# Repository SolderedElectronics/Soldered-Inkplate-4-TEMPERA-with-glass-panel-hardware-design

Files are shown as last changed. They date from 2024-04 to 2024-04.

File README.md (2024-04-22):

## Soldered Inkplate 4 TEMPERA with glass panel hardware design

|  |
| :----------------------------------------------------------: |
|      [Soldered Inkplate 4 TEMPERA with glass panel](https://soldered.com/product/soldered-inkplate-4-tempera/)      |

Inkplate 4 TEMPERA is an easy-to-use, all-in-one device that puts the power of e-paper technology in the palm of your hand. Behind its 3.8-inch, 600×600-pixel e-paper touchscreen, it packs the following features into one compact, elegant package: frontlighting, an abundance of sensors, Wi-Fi and Bluetooth connectivity, a built-in battery, and a low-power operating mode.

## Repository contents

All Soldered hardware is designed in KiCAD, and repositories are organized in the following way:

- CAD folder - contains KiCAD files (Schematics, Board, Panel Board), organized by version. Change log lists all changes between versions.
- OUTPUTS - contains useful files, such as Bill of Materials (BOM), PDF of schematics, 3D .step file of the board and gerber files, organized by version. 

## Want to contribute?

All contributions are welcome, feel free to submit the pull request. If you discover a bug, please submit an issue or pull request. 

## About Soldered

Soldered logo

At Soldered, we design and manufacture a wide selection of electronic products to help you turn your ideas into acts and bring you one step closer to your final project. Our products are intented for makers and crafted in-house by our experienced team in Osijek, Croatia. We believe that sharing is a crucial element for improvement and innovation, and we work hard to stay connected with all our makers regardless of their skill or experience level. Therefore, all our products are open-source. Finally, we always have your back. If you face any problem concerning either your shopping experience or your electronics project, our team will help you deal with it, offering efficient customer service and cost-free technical support anytime. Some of those might be useful for you:

- [Web Store](https://www.soldered.com)
- [Tutorials & Projects](https://learn.soldered.com)
- [Community & Technical support](https://community.soldered.com)
- [Custom PCBs](https://pcb.soldered.com)

## License info

All Soldered open-source hardware (OSH) is under The TAPR Open Hardware License. Read more in the LICENSE file. 

No warranty - all designs in this repository are distributed in the hope that they will be useful, but without any warranty. They are provided "AS IS", therefore without warranty of any kind, either expressed or implied. The entire quality and performance of what you do with the contents of this repository are your responsibility. In no event, Soldered (TAVU) will be liable for your damages, losses, including any general, special, incidental or consequential damage arising out of the use or inability to use the contents of this repository. 

Thank you from your fellow makers at Soldered.

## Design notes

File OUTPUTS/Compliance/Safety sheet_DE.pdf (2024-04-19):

BITTE BEWAHREN SIE DIESE INFORMATIONEN ZUR SPÄTEREN VERWENDUNG AUF.
LESEN SIE VOR DER VERWENDUNG DIESES PRODUKTS ALLE ANWEISUNGEN IN DOKUMENT. Produktname: Inkplate 4 TEMPERA
Die ersten Schritte: Besuchen Sie www.soldered.com, um loszulegen.

## WARNUNGEN

- Dieses Produkt sollte nicht abgedeckt werden und in einer gut belüfteten Umgebung betrieben werden.
- Das Produkt sollte auf einer stabilen, flachen, nicht leitenden Oberfläche aufgestellt werden und nicht mit leitenden Gegenständen in Berührung kommen.
- Der Anschluss anderer Geräte kann die Konformität beeinträchtigen oder zu Schäden am Gerät führen und zum Erlöschen der Garantie führen.
- Wenn Peripheriegeräte angeschlossen werden, die nicht das Kabel oder den Stecker enthalten, muss das verwendete Kabel oder muss das verwendete Kabel bzw. der verwendete Steckverbinder eine angemessene Isolierung und Funktion aufweisen, damit die Anforderungen die einschlägigen Leistungs- und Sicherheitsanforderungen erfüllt werden.
- Es besteht Explosionsgefahr, wenn die Batterie falsch eingesetzt wird.
- Das Produkt sollte nicht außerhalb des angegebenen Arbeitsbereichs verwendet werden.

## HINWEISE ZUR SICHEREN ANWENDUNG

Um Fehlfunktionen oder Schäden an Ihrem Gerät zu vermeiden, beachten Sie bitte die folgenden Hinweise:
- Setzen Sie das Gerät nicht Wasser oder Feuchtigkeit aus und stellen Sie es nicht auf eine
leitende Oberfläche, wenn es eingeschaltet ist. Das Gerät nicht mit nassen Händen anfassen.
- Setzen Sie es keiner Wärmequelle aus; das Produkt ist für die Verwendung bei normalen Raumtemperaturen ausgelegt. Das Produkt ist für die Verwendung in Innenräumen vorgesehen.
- Seien Sie bei der Handhabung vorsichtig, um mechanische oder elektrische Schäden an Teilen des Geräts zu vermeiden. Fassen Sie das Gerät nicht an, wenn es unter Spannung steht. Verwenden Sie einen ESD-Schutz.
- Verwenden Sie nur das mitgelieferte Kabel (oder ein gleich- oder höherwertiges Kabel)
mit dem Gerät.

## COMPLIANCE-INFORMATIONEN

Das Produkt entspricht den entsprechenden Bestimmungen der RoHS-Richtlinie für die Europäische Union. Wie alle elektrischen und elektronischen Geräte (EEE), sollte das Produkt nicht über den Hausmüll entsorgt werden.
ELEKTROMAGNETISCHE VERTRÄGLICHKEIT UND BETRIEB
- Das Produkt entspricht den Schutzanforderungen der Richtlinie des EU-Rates 2014/30/EU über die Rechtsvorschriften der Mitgliedstaaten zur elektromagnetischen Verträglichkeit und den Elektromagnetische Verträglichkeitsverordnung 2016 des Vereinigten Königreichs.
- WARNUNG: Bitte verändern Sie nicht das Design dieses Produkts, da dies dazu führen kann, dass Sie das Produkt nicht mehr uneingeschränkt nutzen können.
Dies gilt auch für die Änderung der Frequenz, mit der das Produkt arbeitet.

## Einhaltung gesetzlicher Vorschriften und wichtige

Soldered Electronics d.o.o., Reisnerova ulica 100, 31000 Osijek, Croatia. VAT ID: HR83200237288

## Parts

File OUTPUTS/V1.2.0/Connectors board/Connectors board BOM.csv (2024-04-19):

Id | Designator | Package | Quantity | Designation | Supplier and ref
1 | H1,H4,H2,H3 | HOLE_3.2mm | 4 | HOLE_3.2mm
2 | K5 | JS05A-40P-050-3-4 | 1 | JS05A-40P-050-3-4
3 | K3 | SFV34R-3STBE1HLF | 1 | SFV34R-3STBE1HLF
4 | R1 | 0603R | 1 | 100k
5 | C4,C7,C3,C5,C6 | 0805C | 5 | 4u7-TMK212AB7475KG-T
6 | C1,C8 | 0603C | 2 | 100n
7 | K4 | 62684-401100AHLF | 1 | 62684-402100AHLF
8 | K1 | SFV6R-1STBE1HLF | 1 | SFV6R-1STBE1HLF
9 | C2 | 0603C | 1 | 4u7
10 | K6 | SFV6R-1STBE1HLF | 1 | DNP
11 | K2 | SFV8R-1STBE1HLF | 1 | SFV8R-1STBE1HLF

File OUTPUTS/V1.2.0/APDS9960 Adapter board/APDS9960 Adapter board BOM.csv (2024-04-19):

Id | Designator | Package | Quantity | Designation | Supplier and ref
1 | R1 | 0603R | 1 | 10k
2 | C2 | 0603C | 1 | 100n
3 | C1 | 0603C | 1 | 1u
4 | U1 | APDS-9960 | 1 | APDS-9960
5 | C3 | 1206C | 1 | 10u
6 | PAD4,PAD3,PAD5,PAD1,PAD2 | PAD_2x1.5 | 5 | PAD_2x1.5

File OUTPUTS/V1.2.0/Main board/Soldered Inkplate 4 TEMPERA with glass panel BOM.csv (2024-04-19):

Id | Designator | Package | Quantity | Designation | Supplier and ref
1 | U10 | TXS0104EPWR | 1 | TXS0104EPWR
2 | D3,D5,D10,D4 | SOD-323 | 4 | BAT20J
3 | K22,K25,K31,K28,K24,K9,K30,K20,K41,K32,K26,K19,K35,K38,K34,K8,K37,K36,K14,K13,K7,K29,K40,K16,K23,K15,K17,K39,K6,K5,K21,K18,K27,K33 | HEADER_MALE_1X1_Inkplate | 34 | HEADER_MALE_1X1_Inkplate
4 | S1 | SK-3296S-01-L1 | 1 | SK-3296S-01-L1
5 | R17,R18,R49 | 0603R | 3 | 5k1
6 | C13,C4,C3,C12,C8,C11,C7,C1,C5,C2 | 0805C | 10 | 4u7-TMK212AB7475KG-T
7 | K4 | easyC-connector | 1 | easyC-SMD
8 | C41,C42,C59,C40,C49,C51,C63,C58,C53,C61,C65,C23,C45,C60,C32,C38,C27,C64,C22,C35,C26,C47,C68,C48,C57,C62,C33,C66 | 0603C | 28 | 100n
9 | K42,K43 | APDS_connector | 2 | APDS_connector
10 | PAD4,PAD2,PAD3,PAD5,PAD1 | PAD_4x4 | 5 | PAD_4x4
11 | R19,R34,R21,R35,R33,R31 | 0603R | 6 | 1k
12 | R39,R38,R42,R41,R36,R3,R43,R52,R47,R44,R5,R51,R53,R60,R4,R37 | 0603R | 16 | 100k
13 | C15,C14 | 0603C | 2 | 2u2-GRM188R61E225MA12D
14 | R10,R6,R8,R9,R7 | 0603R | 5 | 4k7
15 | R11 | 0603R | 1 | NTC-NCP18XH103F03RB
16 | SW3,SW2 | K2-1114SA-A4SW-06 | 2 | K2-1114SA-A4SW-06
17 | JP1,JP4 | SMD_JUMPER | 2 | SMD_JUMPER
18 | R2,R1,R46,R55,R58,R54,R56,R28,R40,R57,R61 | 0603R | 11 | 10k
19 | JP2 | SMD_JUMPER_3_PAD_CONNECTED_RIGHT_TRACE | 1 | SMD_JUMPER_3_PAD_CONNECTED_RIGHT_TRACE
20 | C30,C54 | 2917C | 2 | DNP
21 | SW1 | YTSA007A0151803B | 1 | YTSA007A0151803B
22 | R15,R13 | 0603R | 2 | 1M
23 | C17,C16 | 0603C | 2 | 10n-AC0603KRX7R8BB103
24 | R32 | 0603R | 1 | 47R
25 | C34,C39,C31,C67,C24,C21,C56 | 0603C | 7 | 2u2
26 | H4,H2,H1,H3 | HOLE_3.2mm | 4 | HOLE_3.2mm
27 | K3 | JST-2pin-SMD | 1 | JST-2pin-SMD
28 | JP5 | SMD-JUMPER-CONNECTED_TRACE_SOLDERMASK | 1 | SMD-JUMPER-CONNECTED_TRACE_SOLDERMASK
29 | D9 | LTST-S270GKT | 1 | 0603LED_SIDE
30 | JP6,JP3 | SMD_JUMPER_3_PAD_CONNECTED_LEFT_TRACE | 2 | SMD_JUMPER_3_PAD_CONNECTED_LEFT_TRACE
31 | U19 | BME688 | 1 | BME688
32 | R12 | 0603R | 1 | 43k-RC0603FR-0743KL
33 | Q6,Q7 | SOT-23-3 | 2 | SSM3J358R,LF
34 | U15,U13 | PCAL6416AHF,128 | 2 | PCAL6416AHF,128
35 | Q8,Q11,Q12,Q14,Q9,Q4,Q13 | SOT-23-3 | 7 | PMOS
36 | K10 | HYC77-TF09-200 | 1 | HYC77-TF09-200
37 | U20 | MLT-7525 | 1 | MLT-7525
38 | F1 | 1206FUSE | 1 | 1206FUSE-500mA
39 | D8 | 0402LED | 1 | RED
40 | C9,C10,C6 | 0603C | 3 | 10u-GRM188R61E106KA73J
41 | K11 | CR2032-BS-6-1 | 1 | CR2032_BS-6-1
42 | K1 | INKPLATE TEST HEADER | 1 | Inkplate_TP
43 | K2 | U262-161N-4BVC11 | 1 | U262-161N-4BVC11
44 | D7,D6 | SOT-23-3 | 2 | BAT54S
45 | R63,R26,R20 | 0603R | 3 | DNP
46 | C19,C18 | 0603C | 2 | 100n-AC0603KRX7R8BB104
47 | R16 | 0603R | 1 | 47k5-RC0603FR-0747K5L
48 | C55,C20,C25 | 1206C | 3 | 10u
49 | D11,D12 | M4_DIODA | 2 | M4_DIODA
50 | C36,C37 | 0603C | 2 | 12p
51 | C28 | 0603C | 1 | 470n
52 | U17 | LSM6DSO32TR | 1 | LSM6DS3TR
53 | U6 | SOP-16 | 1 | CH340C
54 | D1,D2 | SOD-323-2 | 2 | CUS10F30,H3F
55 | U2 | SOT-23-5 | 1 | MCP73831T
56 | D13 | SOD-523 | 1 | RB510SM-40FHT2R
57 | U14 | ESP32-WROVER | 1 | ESP32-WROVER
58 | U11 | SN74LVC1G34DBV | 1 | SN74LVC1G34DBV
59 | C52,C50 | 0805C | 2 | CL21B105KBFNNNG
60 | U3 | TPS7A2633DRVR | 1 | TPS7A2633DRVR
61 | Q5,Q3,Q2 | SOT-23-3 | 3 | NPN
62 | L3 | NR4012 | 1 | NR4012T220M
63 | C43 | 0603C | 1 | 4u7
64 | R24 | 0603R | 1 | PA0603FRE570R01L
65 | R30,R29 | 0603R | 2 | 33k
66 | Q15,Q10 | SOT-23-3 | 2 | NMOS
67 | U8 | PCF85063A | 1 | PCF85063A
68 | C46 | 0603C | 1 | 100p
69 | K12 | 62684-401100AHLF | 1 | 62684-401100AHLF
70 | X1 | ABS07AIG-32.768KHZ-7-D-T | 1 | 7LC32768F12UC
71 | R14 | 0603R | 1 | 52k3-RC0603FR-0752K3L
72 | R23 | 0603R | 1 | 2k49
73 | C29,C44 | 0603C | 2 | 1u
74 | U16 | SC70-6 | 1 | MCP4017T-103E/LT
75 | L1 | 1515L | 1 | LQH44PN4R7MP0L
76 | R22 | 0603R | 1 | 0R
77 | U7 | TSSOP-14 | 1 | MC14093BDTR2G
78 | U4 | SOT-23-5 | 1 | TPS3840PL27DBVR
79 | R62 | 0603R | 1 | 22
80 | U9 | MCP47A1-SOT23-6 | 1 | MCP47A1
81 | R48 | 0603R | 1 | 15R
82 | R27,R50 | 0603R | 2 | 47k
83 | R25 | 0603R | 1 | 1M8
84 | R45 | 0603R | 1 | 330R
85 | U12 | SOT26 | 1 | AP5726WG-7
86 | U18 | SOIC−8 | 1 | TLC555CDR
87 | R59 | 0603R | 1 | 2k2
88 | Q1 | SOT-23-3 | 1 | DNP
89 | U1 | VQFN-49_V2 | 1 | TPS65186RGZR
90 | U5 | BQ27441 | 1 | BQ27441DRZR-G1A
91 | L2 | NR4012 | 1 | NR4012T2R2M

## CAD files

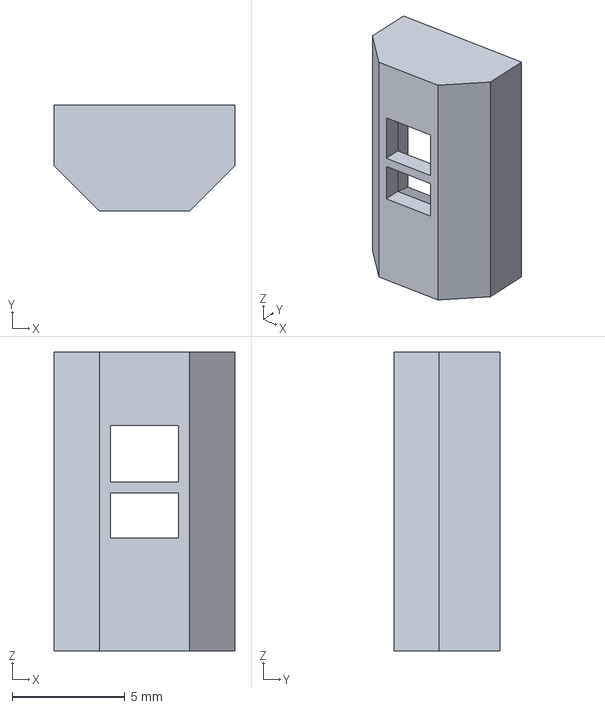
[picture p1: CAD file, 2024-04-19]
CAD/V1.2.0/Source 3D files/APDS 9960 slot Inkplate 4 TEMPERA v1.0.3..step
8.00 x 4.70 x 13.2 mm

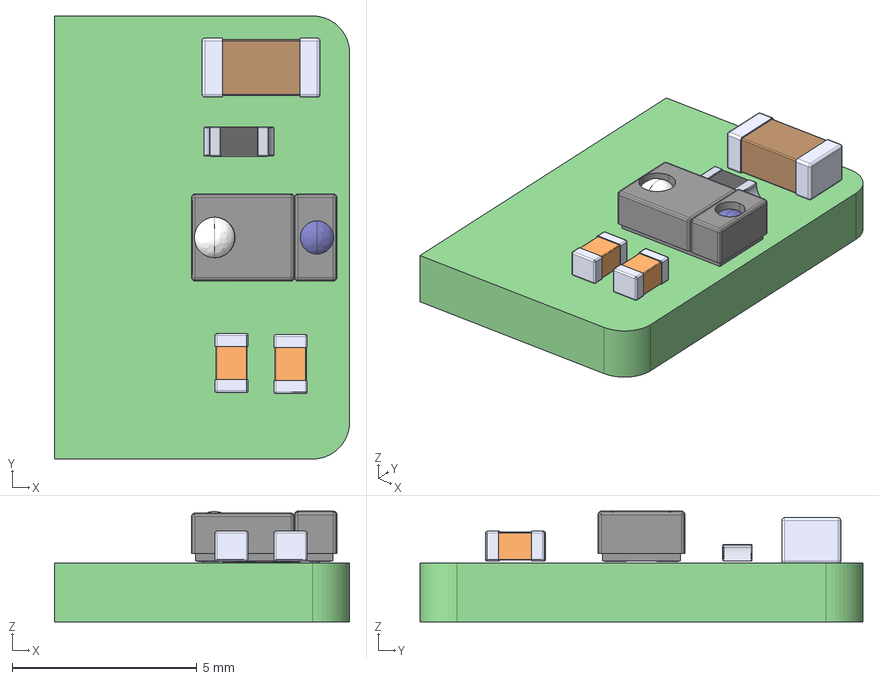
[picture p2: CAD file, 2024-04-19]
OUTPUTS/V1.2.0/APDS9960 Adapter board/APDS9960 Adapter board 3D.step
8.00 x 12.0 x 3.00 mm
APDS9960 Adapter board PCB

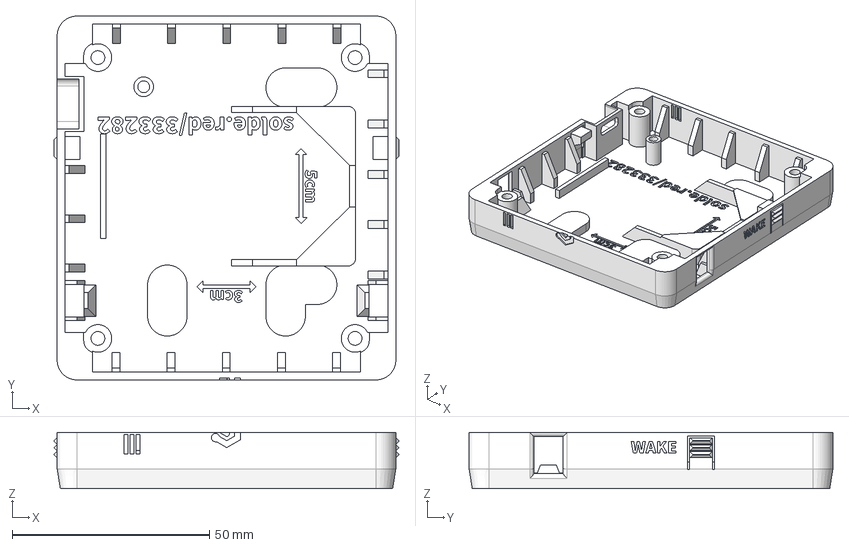
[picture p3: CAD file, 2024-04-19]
CAD/V1.2.0/Source 3D files/Inkplate 4 TEMPERA BOTTOM v1.0.3..step
87.5 x 92.3 x 14.2 mm

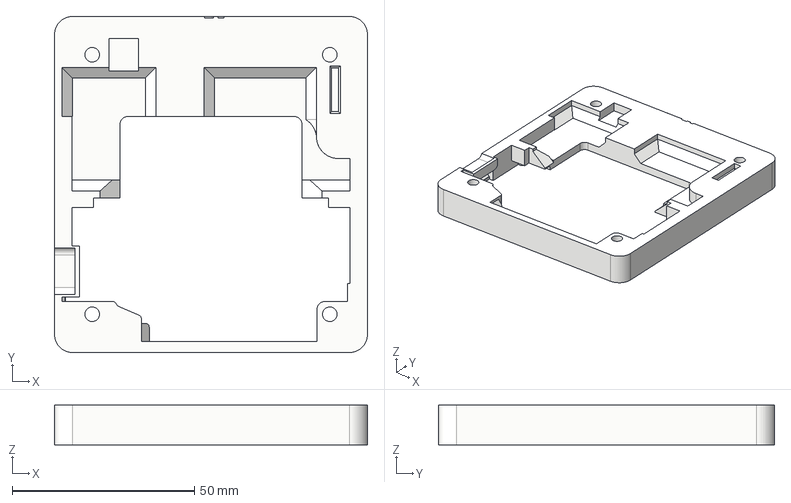
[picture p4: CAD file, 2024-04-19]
CAD/V1.2.0/Source 3D files/Inkplate 4 TEMPERA TOP v1.0.3..step
85.9 x 92.2 x 10.9 mm

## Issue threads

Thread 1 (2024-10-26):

INKPLATE 4 TEMPERA - fast battery discharge

yuri-273, 2024-10-26:
I wrote a sketch that updates the screen once a minute.
The battery life is about three hours.
How to find out what is the problem of fast battery discharge?

rsoric, 2024-10-28:
Hi @yuri-273

thanks for your question, are you using deep sleep between screen updates? It's recommended to use deep sleep to save power and wake every minute. Check out [this ](https://github.com/SolderedElectronics/Inkplate-Arduino-library/blob/master/examples/Inkplate4TEMPERA/Advanced/DeepSleep/Inkplate4TEMPERA_Simple_Deep_Sleep/Inkplate4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)code example.

-Rob

yuri-273, 2024-10-30:
esp_light_sleep - 1 min.
Work time - 7:34

yuri-273, 2024-11-02:
Thanks for your help.
I added from the sketch Inkplate4TEMPERA_Simple_Deep_Sleep.ino: disable GPIO12, disable touchscreen, disable frontlight.
Has been working for more than 12 hours.

**The sketch i used:**
`/*
   CLOCK FOR NKPLATE 4 TEMPERA
*/

// Next 3 lines are a precaution, you can ignore those, and the example would also work without them
#ifndef ARDUINO_INKPLATE4TEMPERA
#error "Wrong board selection for this example, please select Inkplate 4 TEMPERA in the boards menu."
#endif

#include <Inkplate.h>            // Include Inkplate library to the sketch
Inkplate display(INKPLATE_1BIT); // Create an object on Inkplate library and also set library into 1-bit mode (BW)
#include "driver/rtc_io.h" //ESP32 library used for deep sleep and RTC wake up pins

#include <WiFi.h>
#include <time.h>

const char* ssid       = "XXX";
const char* password   = "XXX";

// Delay esp light sleep
#define DELAY_MS 59000 // 59 sec

const char* ntpServer = "pool.ntp.org";
const long  gmtOffset_sec = 7200;
// For UTC -5.00 : -5 * 60 * 60 = -18000
// For UTC +1.00 : 1 * 60 * 60 = 3600
// For UTC +0.00 : 0 * 60 * 60 = 0
//const int   daylightOffset_sec = 3600;
const int   daylightOffset_sec = 0;
// Change the Daylight offset in seconds. If your country observes Daylight saving time set it to 3600. Otherwise, set it to 0.

// Set var clock
uint8_t hour;
uint8_t minutes;
uint8_t seconds;

// Set date and weekday (NOTE: In weekdays 0 means Sunday, 1 menas Monday, ...)
uint8_t weekday;
uint8_t day;
uint8_t month;
int16_t year; //2 digits

// Variable that keeps count on how much screen has been partially updated if (n > 9)
int n = 0;

void setup()

{
  Serial.begin(115200);

  Serial.println(F("Rev.2024.11.01"));
  Serial.println(F("INKPLATE 4 TEMPERA"));
  Serial.print(F("The compilation date of the current source file: "));
  Serial.print(__DATE__);
  Serial.print(F(" "));
  Serial.println(__TIME__);

  connectWifi();
  delay(500);

  // Get the correct time from NTP
  configTime(gmtOffset_sec, daylightOffset_sec, ntpServer);

  struct tm timeinfo;
  if (!getLocalTime(&timeinfo)) {
    Serial.println(F("Failed to obtain time"));
    return;
  }
  Serial.println(F("Setup local time from NTP"));
  Serial.println(&timeinfo, "%H:%M:%S %A, %d/%B/%Y");

  //======== BEGIN setup local time from NTP ========//
  uint8_t hour = timeinfo.tm_hour; // hours since midnight 0-23
  uint8_t minutes = timeinfo.tm_min; // minutes after the hour 0-59
  uint8_t seconds = timeinfo.tm_sec; // seconds after the minute 0-60

  uint8_t weekday = timeinfo.tm_wday; // days since Sunday 0-6
  uint8_t day = timeinfo.tm_mday; // day of the month 1-31
  uint8_t month = timeinfo.tm_mon + 1; // months since January 0-11
  int16_t year = timeinfo.tm_year + 1900; // years since 1900
  //======== END setup local time from NTP ========//

  Serial.println();
  Serial.println(F("Local NTP time from value"));
  Serial.print(F("Hour: "));
  Serial.println( hour );
  Serial.print(F("Minute: "));
  Serial.println( minutes );
  Serial.print(F("Second: "));
  Serial.println( seconds );

  Serial.print(F("Weekday: "));
  Serial.println( weekday );
  Serial.print(F("Day of Month: "));
  Serial.println( day );
  Serial.print(F("Month: "));
  Serial.println( month );
  Serial.print(F("Year: "));
  Serial.println( year );
  Serial.println();

  WiFi.disconnect();

  display.begin();        // Init Inkplate library (you should call this function ONLY ONCE)
  display.clearDisplay(); // Clear frame buffer of display
  display.display();      // Put clear image on display

  //======== BEGIN Setting NTP time in RTC ========//
  display.rtcSetTime(hour, minutes, seconds); // Send time to RTC
  display.rtcSetDate(weekday, day, month, year); // Send date to RTC
  //======== END Setting NTP time in RTC ========//
}

void loop()
{

  display.rtcGetRtcData();             // Get the time and date from RTC
  seconds = display.rtcGetSecond();  // Store senconds in a variable from RTC
  minutes = display.rtcGetMinute();  // Store minutes in a variable from RTC
  hour = display.rtcGetHour();       // Store hours in a variable from RTC
  day = display.rtcGetDay();         // Store day of month in a variable from RTC
  weekday = display.rtcGetWeekday(); // Store day of week in a variable from RTC
  month = display.rtcGetMonth();     // Store month in a variable from RTC
  year = display.rtcGetYear();       // Store year in a variable from RTC

  display.clearDisplay();                                       // Clear content in frame buffer

  //  printRTC_Time(hour, minutes, seconds, day, weekday, month, year); // Print the RTC time on screen
  Serial.println(F("Print the RTC time on screen"));
  printRTC_Time(hour, minutes, seconds, day, weekday, month, year); // Print the RTC time on screen

  if (n > 30) // Check if you need to do full refresh or you can do partial update
  {
    //    display.display(true); // Do a full refresh
    display.display(); // Do a full refresh
    n = 0;
    Serial.println(F("Displays all data in frame buffer to screen"));
  }
  else
  {
    //    display.partialUpdate(false, true); // Do partial update and keep e-papr power supply on
    display.partialUpdate();
    n++;                                // Keep track on how many times screen has been partially updated
    Serial.println("Partial update n=" + String(n));
  }

  // Turn off touchscreen and frontlight to save energy duiring light sleep
  display.tsShutdown();  // Turn off the display touchscreen
  display.frontlight(0); // Turn off the frontlight

  rtc_gpio_isolate(GPIO_NUM_12); // Isolate/disable GPIO12 on ESP32 (only to reduce power consumption in sleep)

  // Go to sleep before checking again
  Serial.println(F("esp_light_sleep"));
  delay(200);
  esp_sleep_enable_timer_wakeup(1000L * DELAY_MS);
  (void)esp_light_sleep_start(); // Sleep 59 sec

  display.rtcGetRtcData();             // Get the time and date from RTC
  while (display.rtcGetSecond() != 0) {
    delay(1000);
    display.rtcGetRtcData();
    Serial.println(display.rtcGetSecond());
  }
  Serial.println(String(display.rtcGetHour()) + ":" + String(display.rtcGetMinute()) + ":" + String(display.rtcGetSecond()));
  //Go to up
}

//======== BEGIN Print RTC Time ========//
void printRTC_Time(uint8_t _hour, uint8_t _minutes, uint8_t _seconds, uint8_t _day, uint8_t _weekday, uint8_t _month,
                   uint16_t _year)
{
  // Write time and date info on screen
  char *wday[] = {"Sunday", "Monday", "Tuesday", "Wednesday", "Thursday", "Friday", "Saturday"};
  display.setTextSize(16); // Set size text
  display.setCursor(70, 100);
  print2Digits(_hour);
  display.print(':');
  print2Digits(_minutes);
  //  display.print(':');
  //  print2Digits(_seconds);

  display.setTextSize(5);
  display.setCursor(160, 240);
  display.print(wday[_weekday]);
  display.setCursor(160, 300);

  print2Digits(_day);
  display.print('/');
  print2Digits(_month);
  display.print('/');
  display.print(_year, DEC);
}

//========END Print RTC Time ========//

//======== BEGIN ADDITION "0"  ========//
void print2Digits(uint8_t _d)
{
  if (_d < 10)
    display.print('0');
  display.print(_d, DEC);
}
//======== END ADDITION "0"  ========//

//======== BEGIN WIFI CONNECT ========//
void connectWifi()
{

  int ConnectCount = 20;

  if (WiFi.status() != WL_CONNECTED)
  {
    while (WiFi.status() != WL_CONNECTED)
    {
      if (ConnectCount++ == 20)
      {
        Serial.println(F("Connect WiFi"));
        WiFi.begin(ssid, password);
        Serial.println(F("Connecting"));
        ConnectCount = 0;
      }
      Serial.print(F("."));
      delay(1000);
    }

    // Information printing
    Serial.println(F("Connected WiFi"));
    Serial.println(WiFi.SSID());
    Serial.print(F("IP address: "));
    Serial.println(WiFi.localIP());
    Serial.print(F("Subnet mask address: "));
    Serial.println(WiFi.subnetMask());
    Serial.print(F("Gateway IP address: "));
    Serial.println(WiFi.gatewayIP());
    Serial.print(F("MAC Address: "));
    Serial.println(WiFi.macAddress());
    Serial.print(F("Current RSSI (Received Signal Strength) "));
    Serial.print(WiFi.RSSI());
    Serial.println(F(" dBm"));

    Serial.println();
  }
}
//======== END WIFI CONNECT ========//
`

yuri-273, 2024-11-02:
What else can be turned off to improve energy efficiency?

rsoric, 2024-11-04:
Hi @yuri-273,

glad this has worked out :) Have a look at the function [sleepPeripheral ](https://github.com/SolderedElectronics/Inkplate-Arduino-library/blob/2dd263f2f9548aadac8638413a143beddf068a64/src/boards/Inkplate4TEMPERA.cpp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)(which is the counterpart to wakePeripheral), you can pass INKPLATE_ACCELEROMETER, INKPLATE_BME688, INKPLATE_APDS9960 and INKPLATE_FUEL_GAUGE to turn off these peripherals.

Give that a try and let me know if it improves the sleep time

-Rob

yuri-273, 2024-11-09:
Hi rsoric.
The **sleepPeripheral** function is already included in the **begin** function, and that is good.
Thanks.

yuri-273, 2024-11-09:
I'm still experimenting with how long the device can last.
At the moment the INKPLATE 4 TEMPERA has been working for more than 10 days.
I think we can close this issues :)
Thanks.

rsoric, 2024-11-11:
@yuri-273 ,

ah you're right, we actually did include it in the driver in that way. Glad it's working well, closing the issue.

-Rob

Closed 2024-11-11.

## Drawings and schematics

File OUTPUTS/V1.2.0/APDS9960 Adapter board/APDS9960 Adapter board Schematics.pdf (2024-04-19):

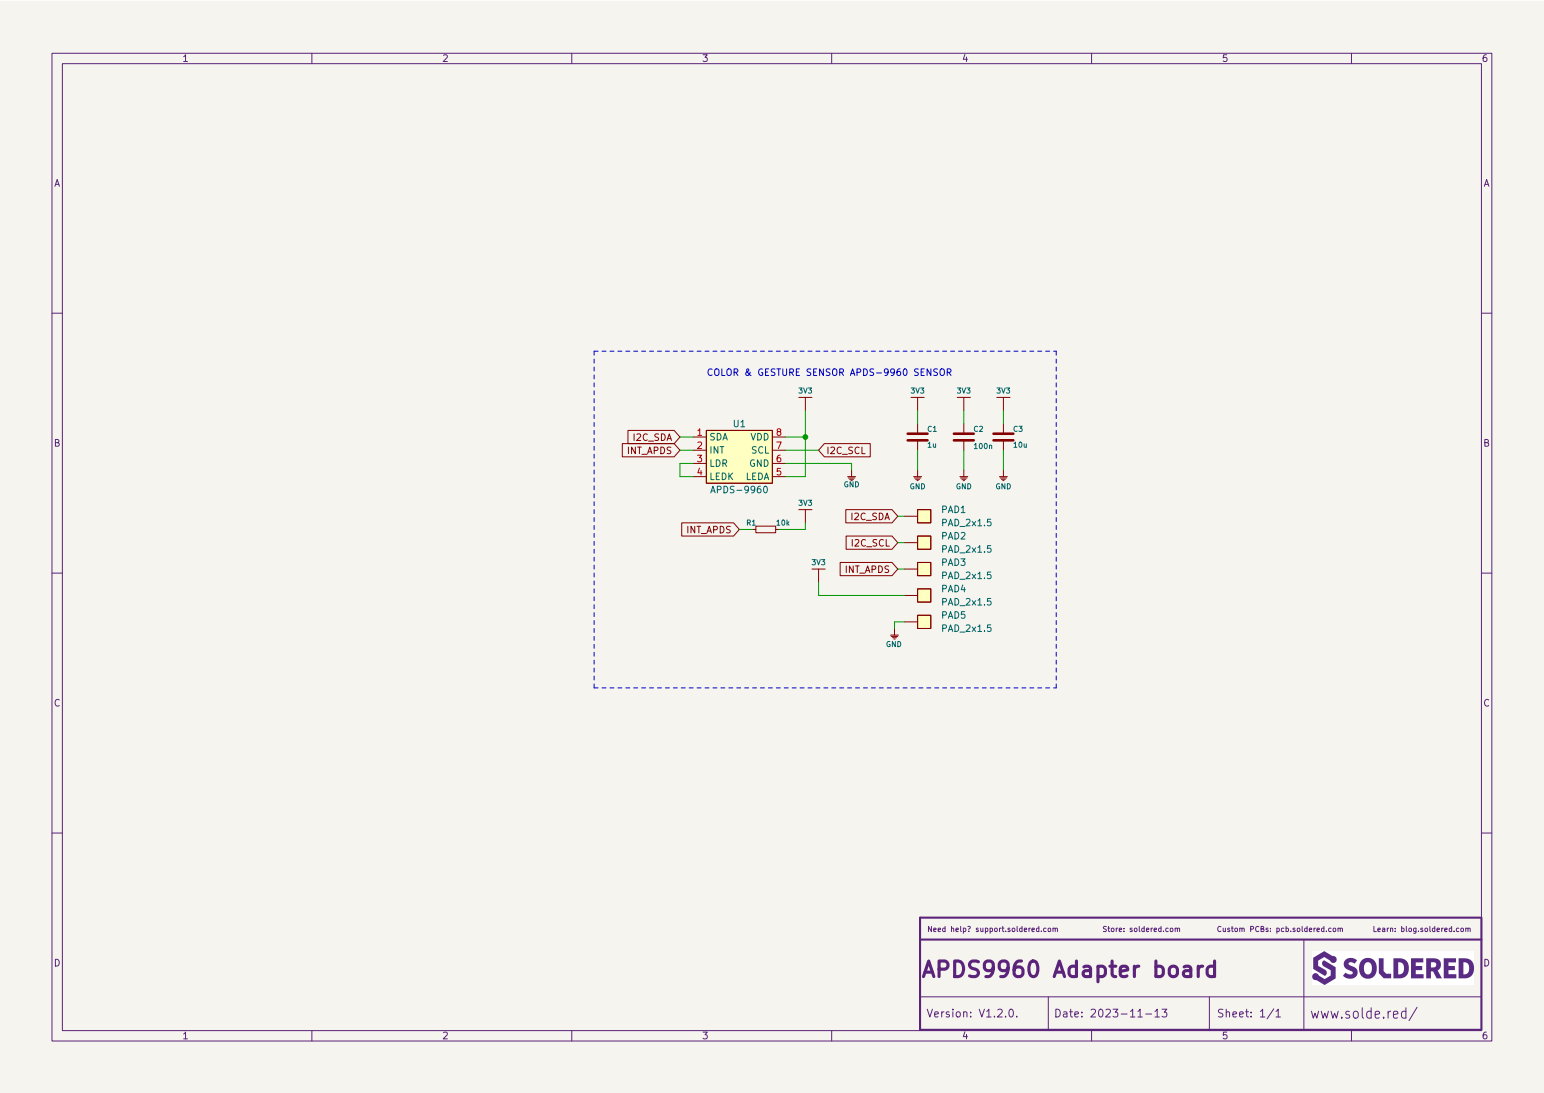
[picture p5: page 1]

Learn: blog.soldered.com

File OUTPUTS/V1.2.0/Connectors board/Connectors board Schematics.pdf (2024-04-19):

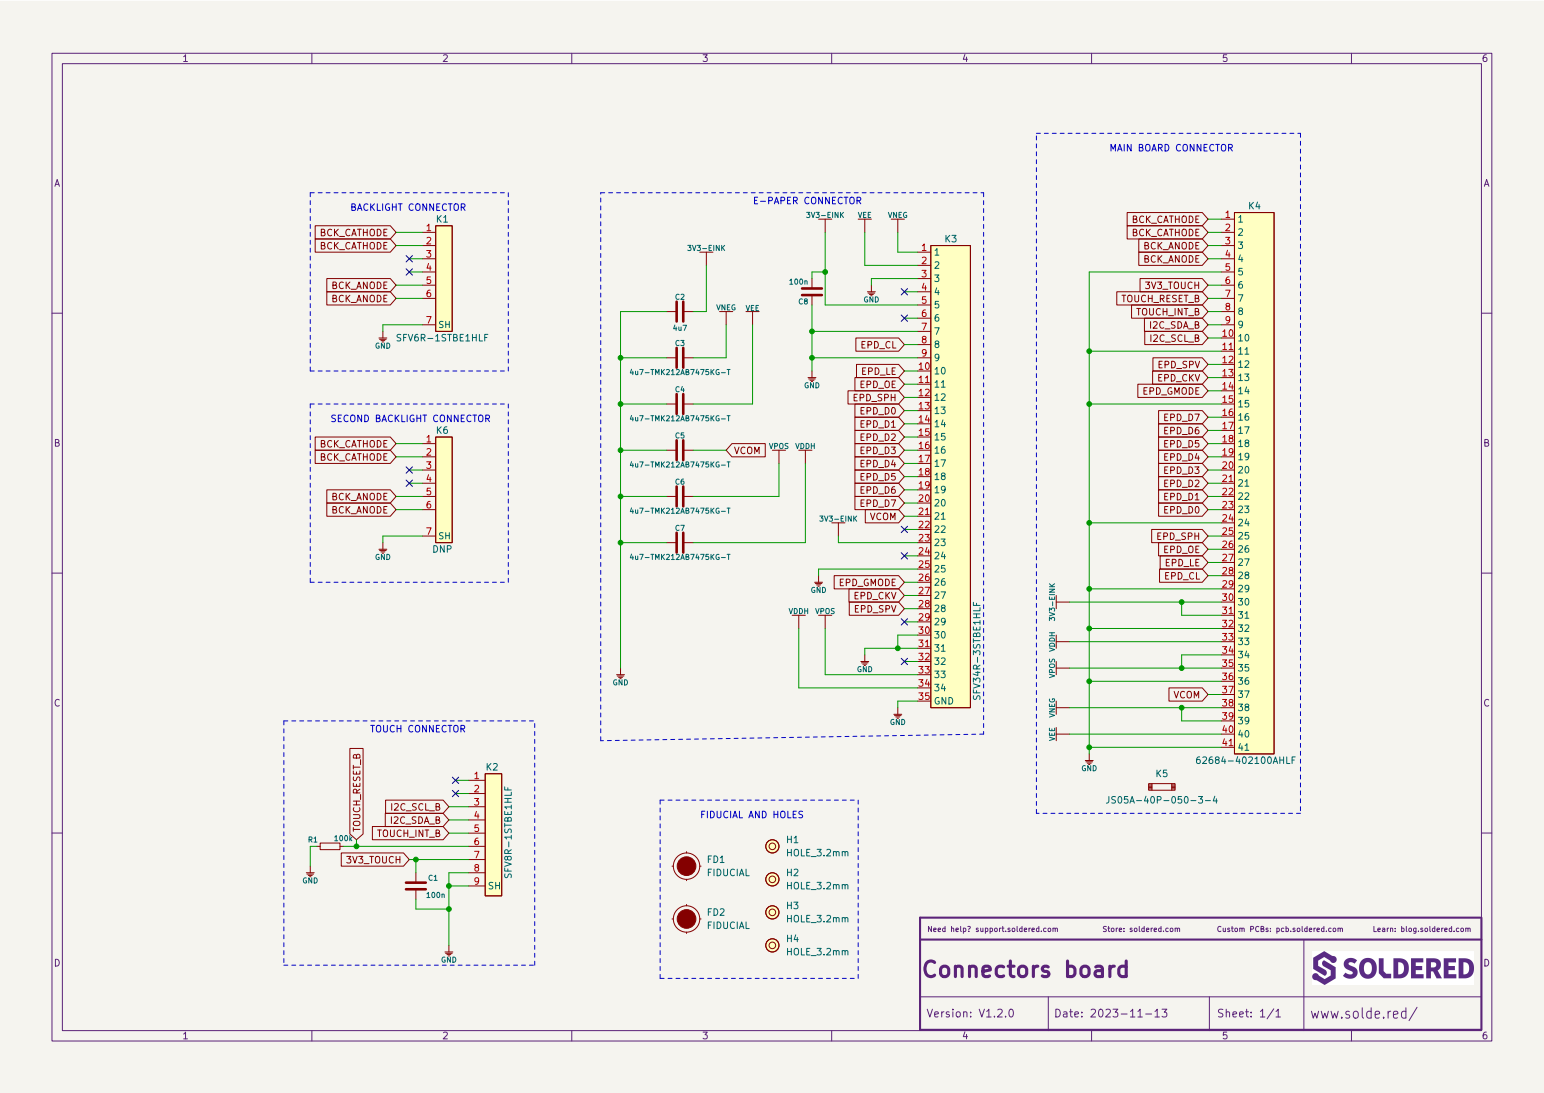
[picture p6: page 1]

E-PAPER CONNECTOR BACKLIGHT CONNECTOR

30 30
31 31

Learn: blog.soldered.com

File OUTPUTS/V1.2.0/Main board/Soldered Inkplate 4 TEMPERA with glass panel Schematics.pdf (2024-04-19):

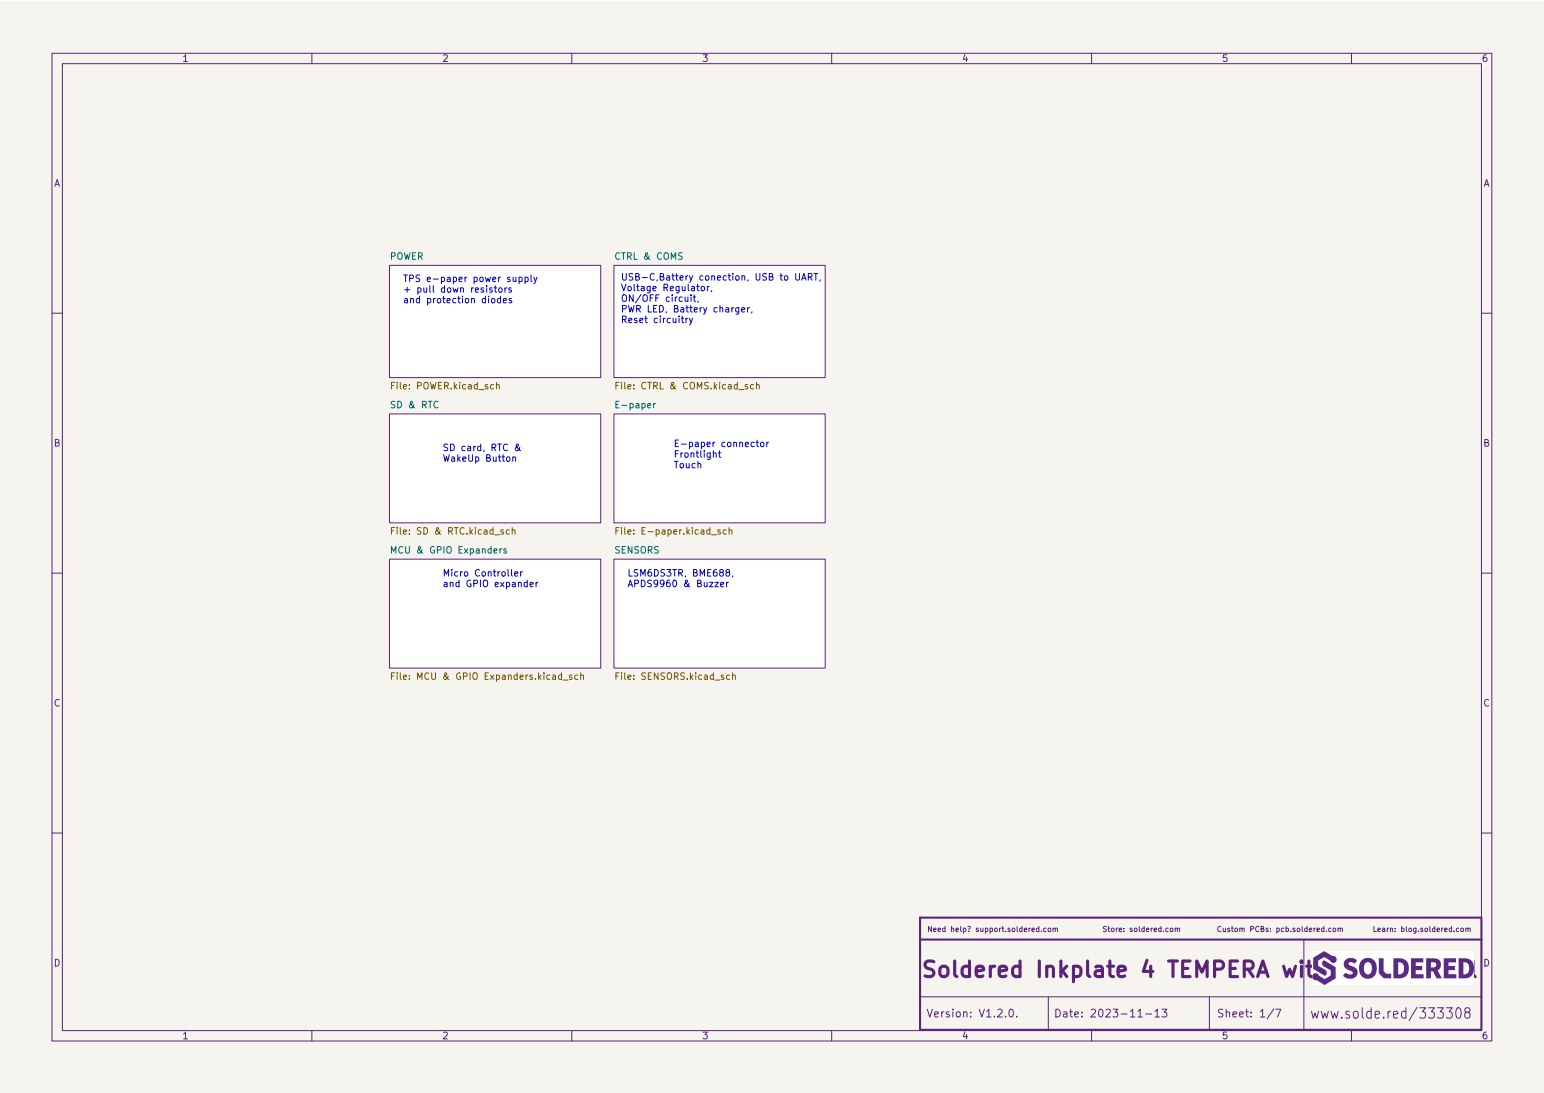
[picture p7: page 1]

and protection diodes SD card, RTC & WakeUp Button Micro Controller and GPIO expander
Reset circuitry LSM6DS3TR, BME688, APDS9960 & Buzzer

File: SENSORS.kicad_sch CTRL & COMS
Frontlight Touch USB-C,Battery conection, USB to UART,
Voltage Regulator, ON/OFF circuit, PWR LED, Battery charger,

File: CTRL & COMS.kicad_sch TPS e-paper power supply
+ pull down resistors

File: POWER.kicad_sch MCU & GPIO Expanders
File: MCU & GPIO Expanders.kicad_sch SD & RTC

Learn: blog.soldered.com

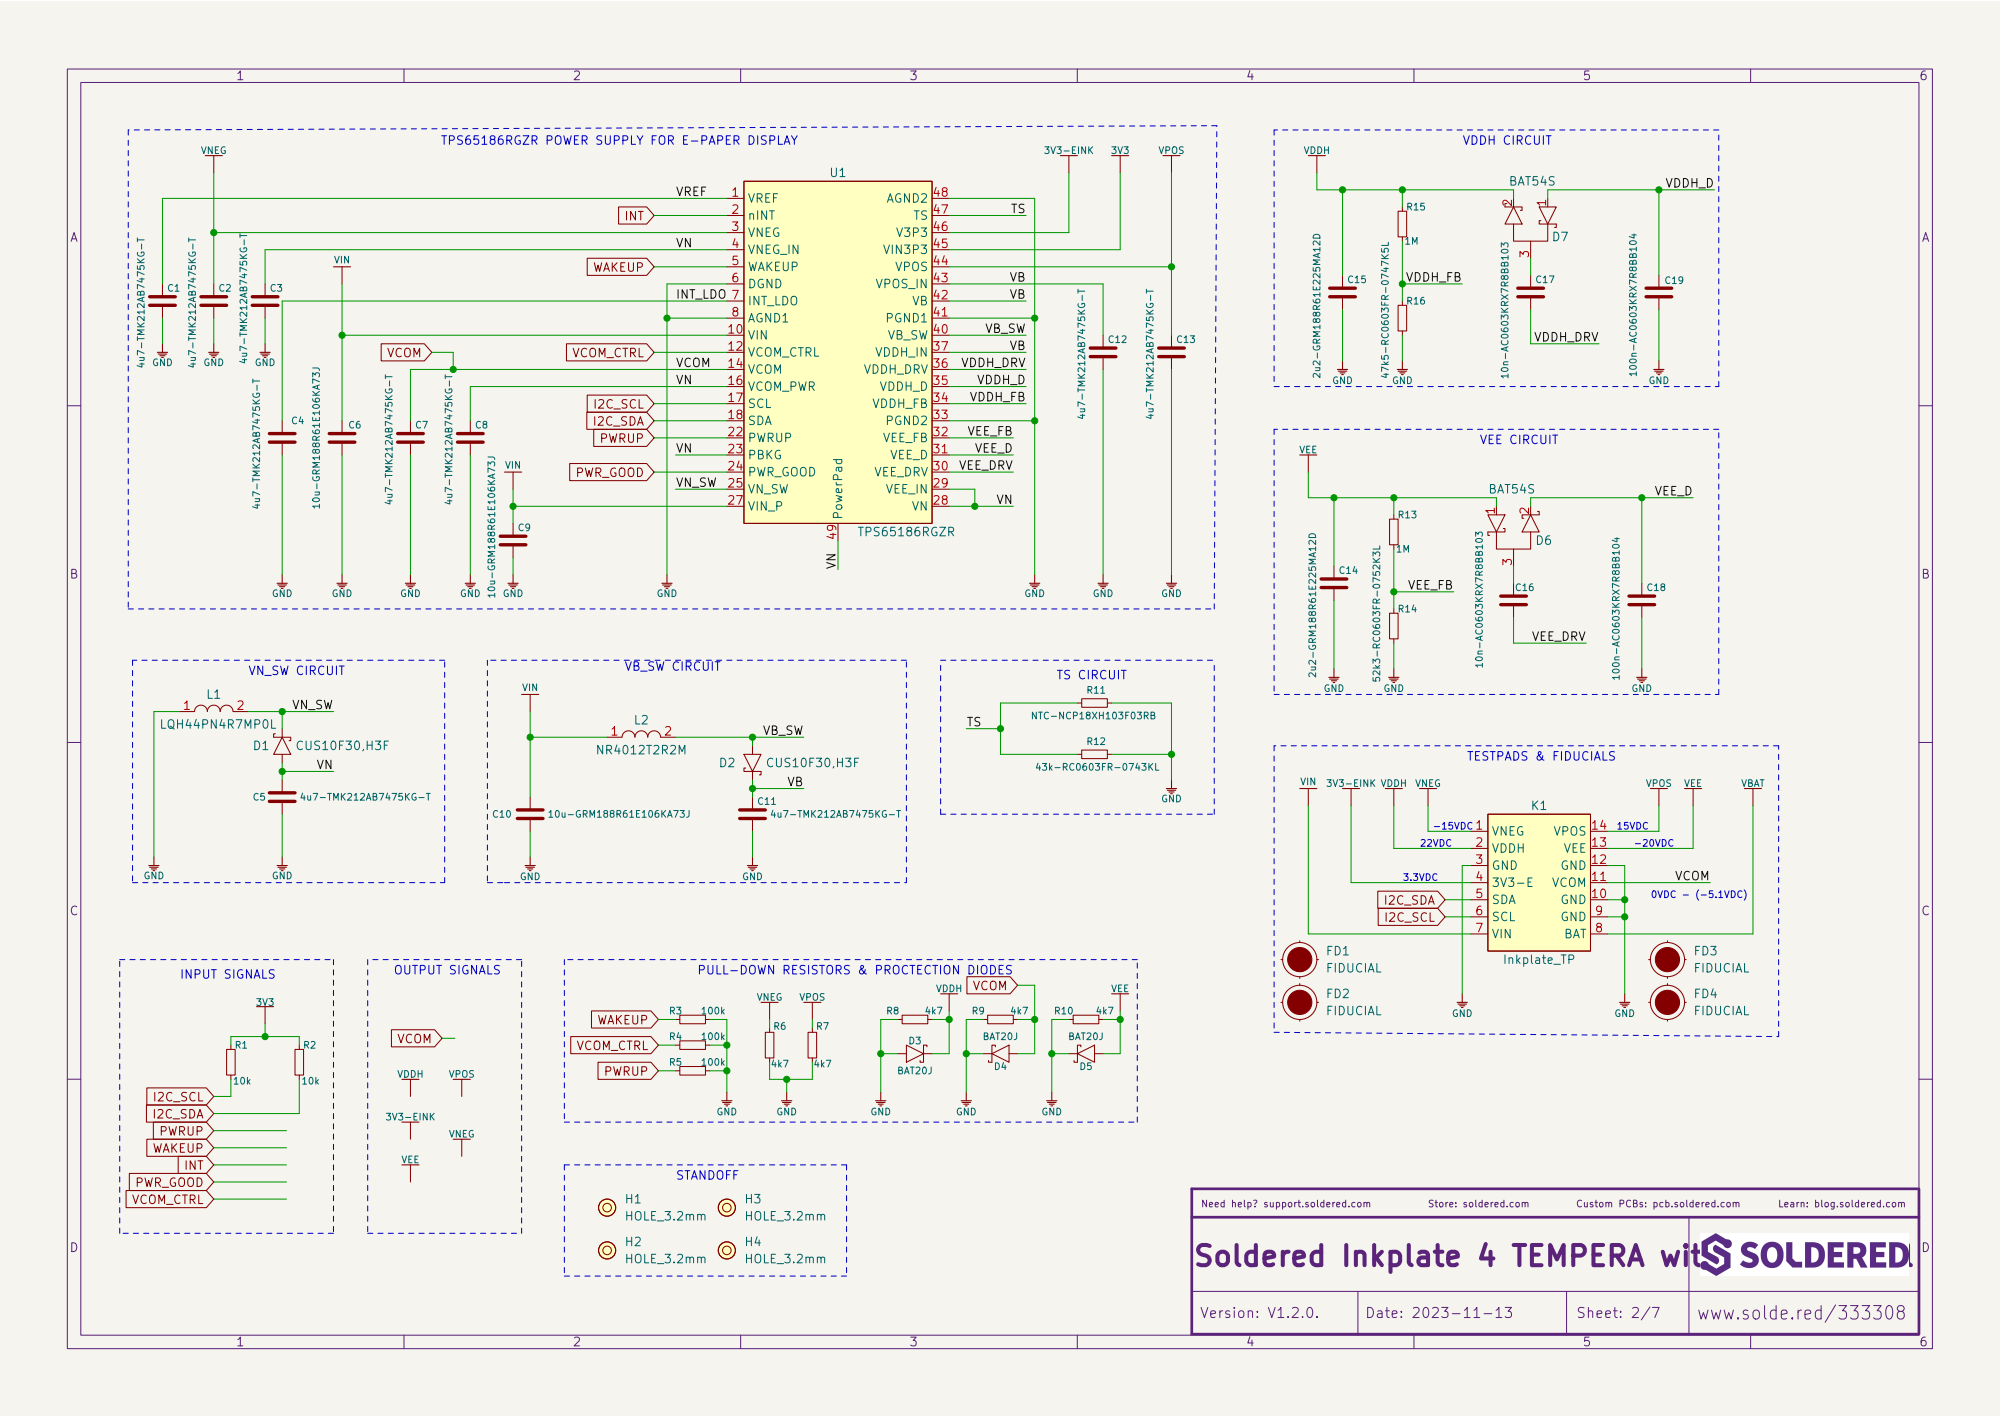
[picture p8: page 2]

VDDH CIRCUIT OUTPUT SIGNALS
VCOM_CTRL PWRUP WAKEUP

TPS65186RGZR POWER SUPPLY FOR E-PAPER DISPLAY

VREF 1 VIN 10 VCOM_CTRL 12 VCOM 14 VCOM_PWR 16 SCL 17 SDA 18

VCOM

VEE | VEE CIRCUIT

TS CIRCUIT PULL-DOWN RESISTORS & PROCTECTION DIODES

Learn: blog.soldered.com

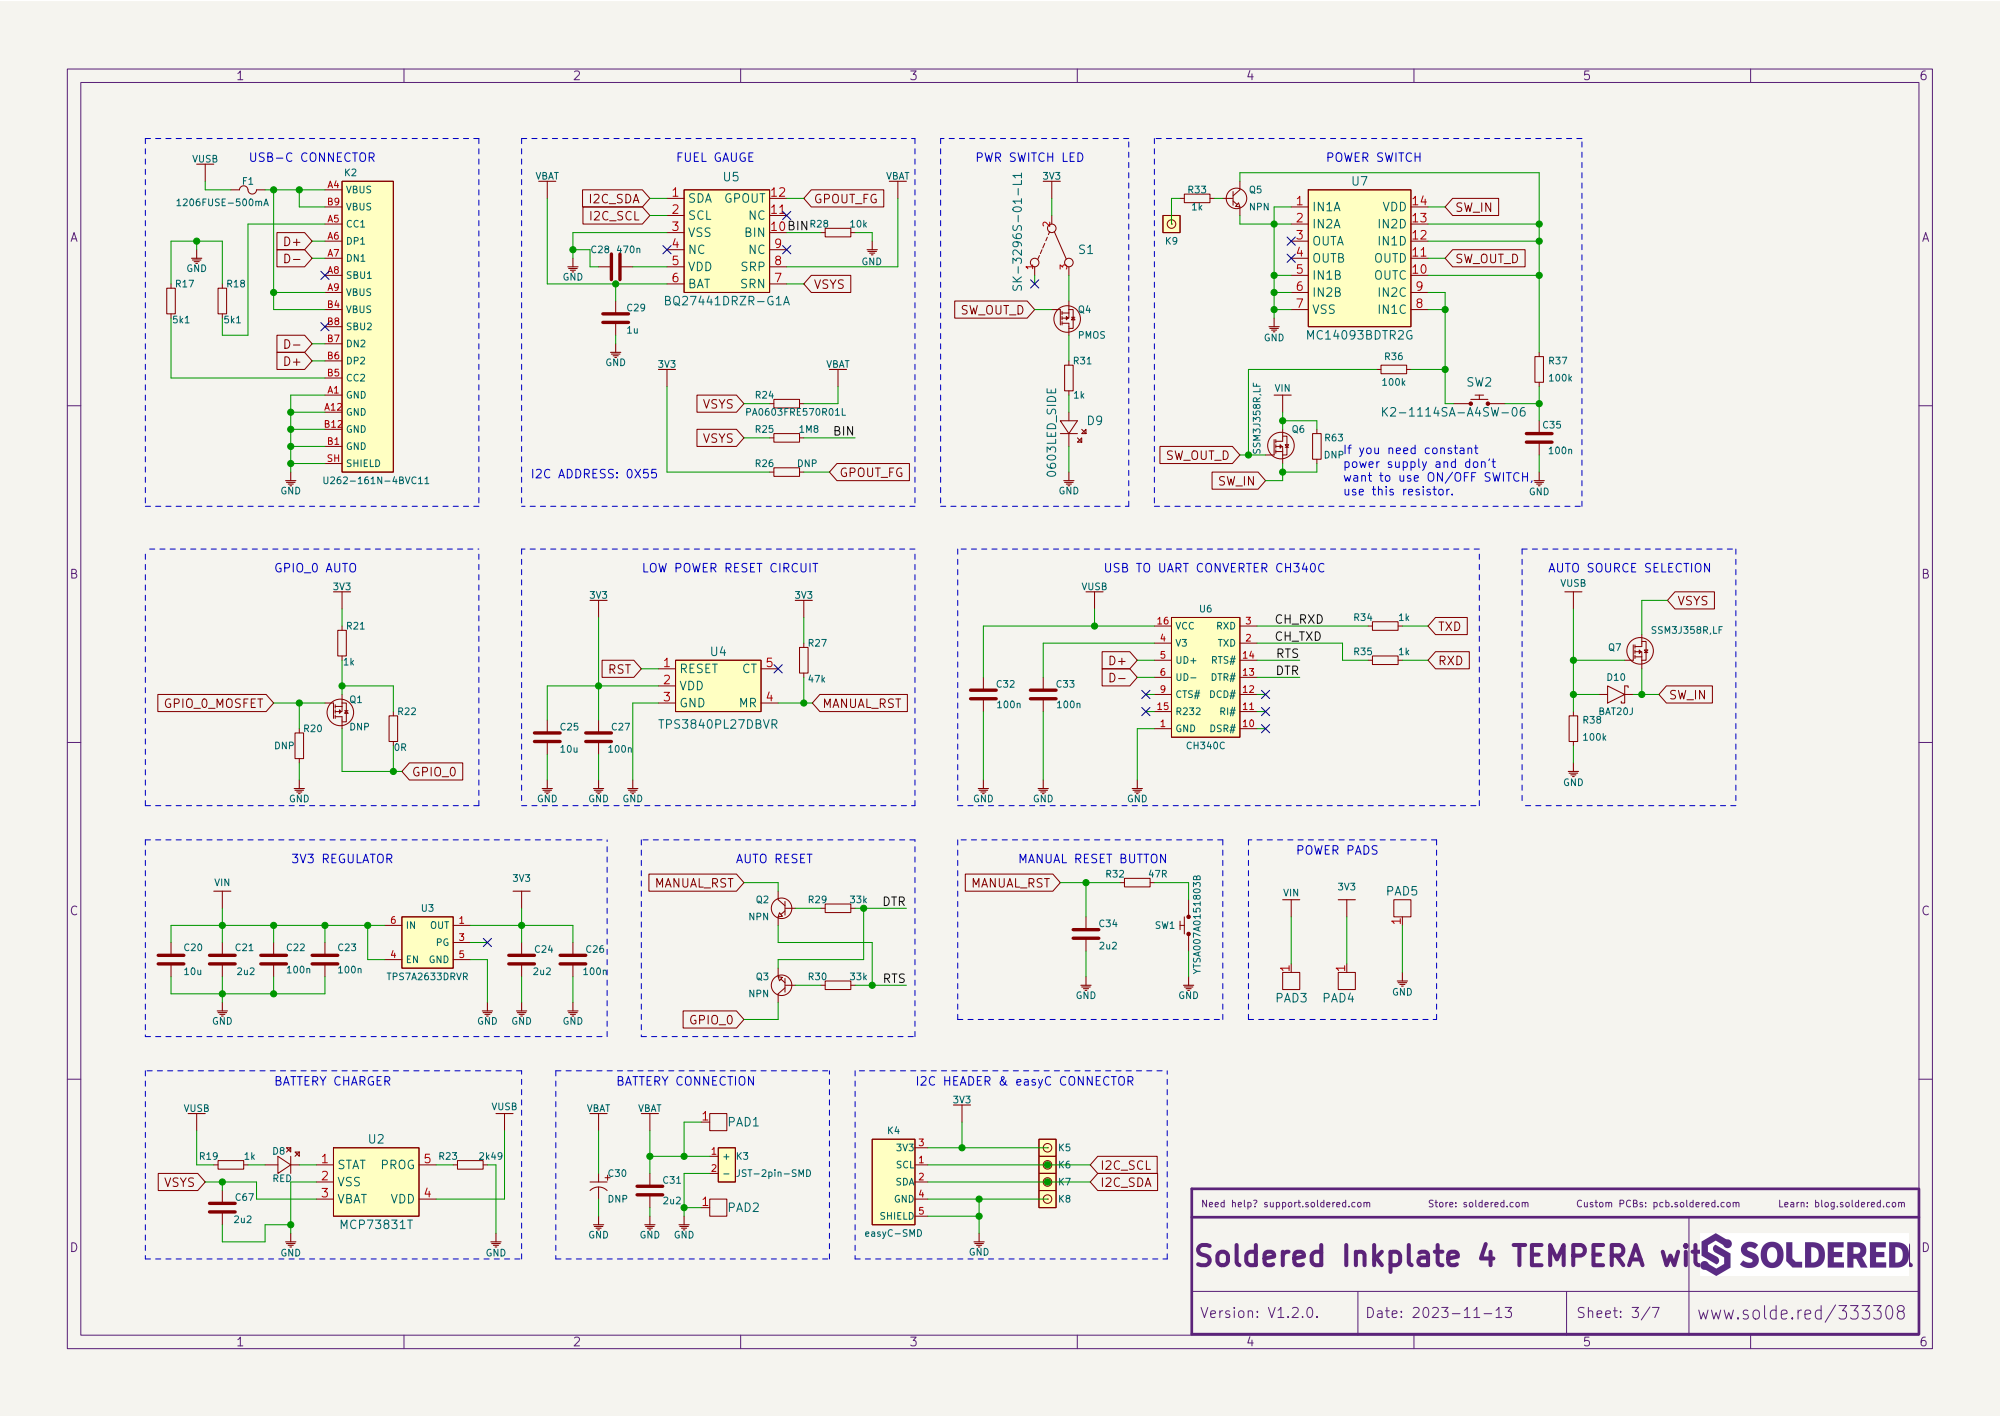
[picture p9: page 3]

If you need constant
power supply and don't want to use ON/OFF SWITCH, use this resistor.

LOW POWER RESET CIRCUIT

Learn: blog.soldered.com

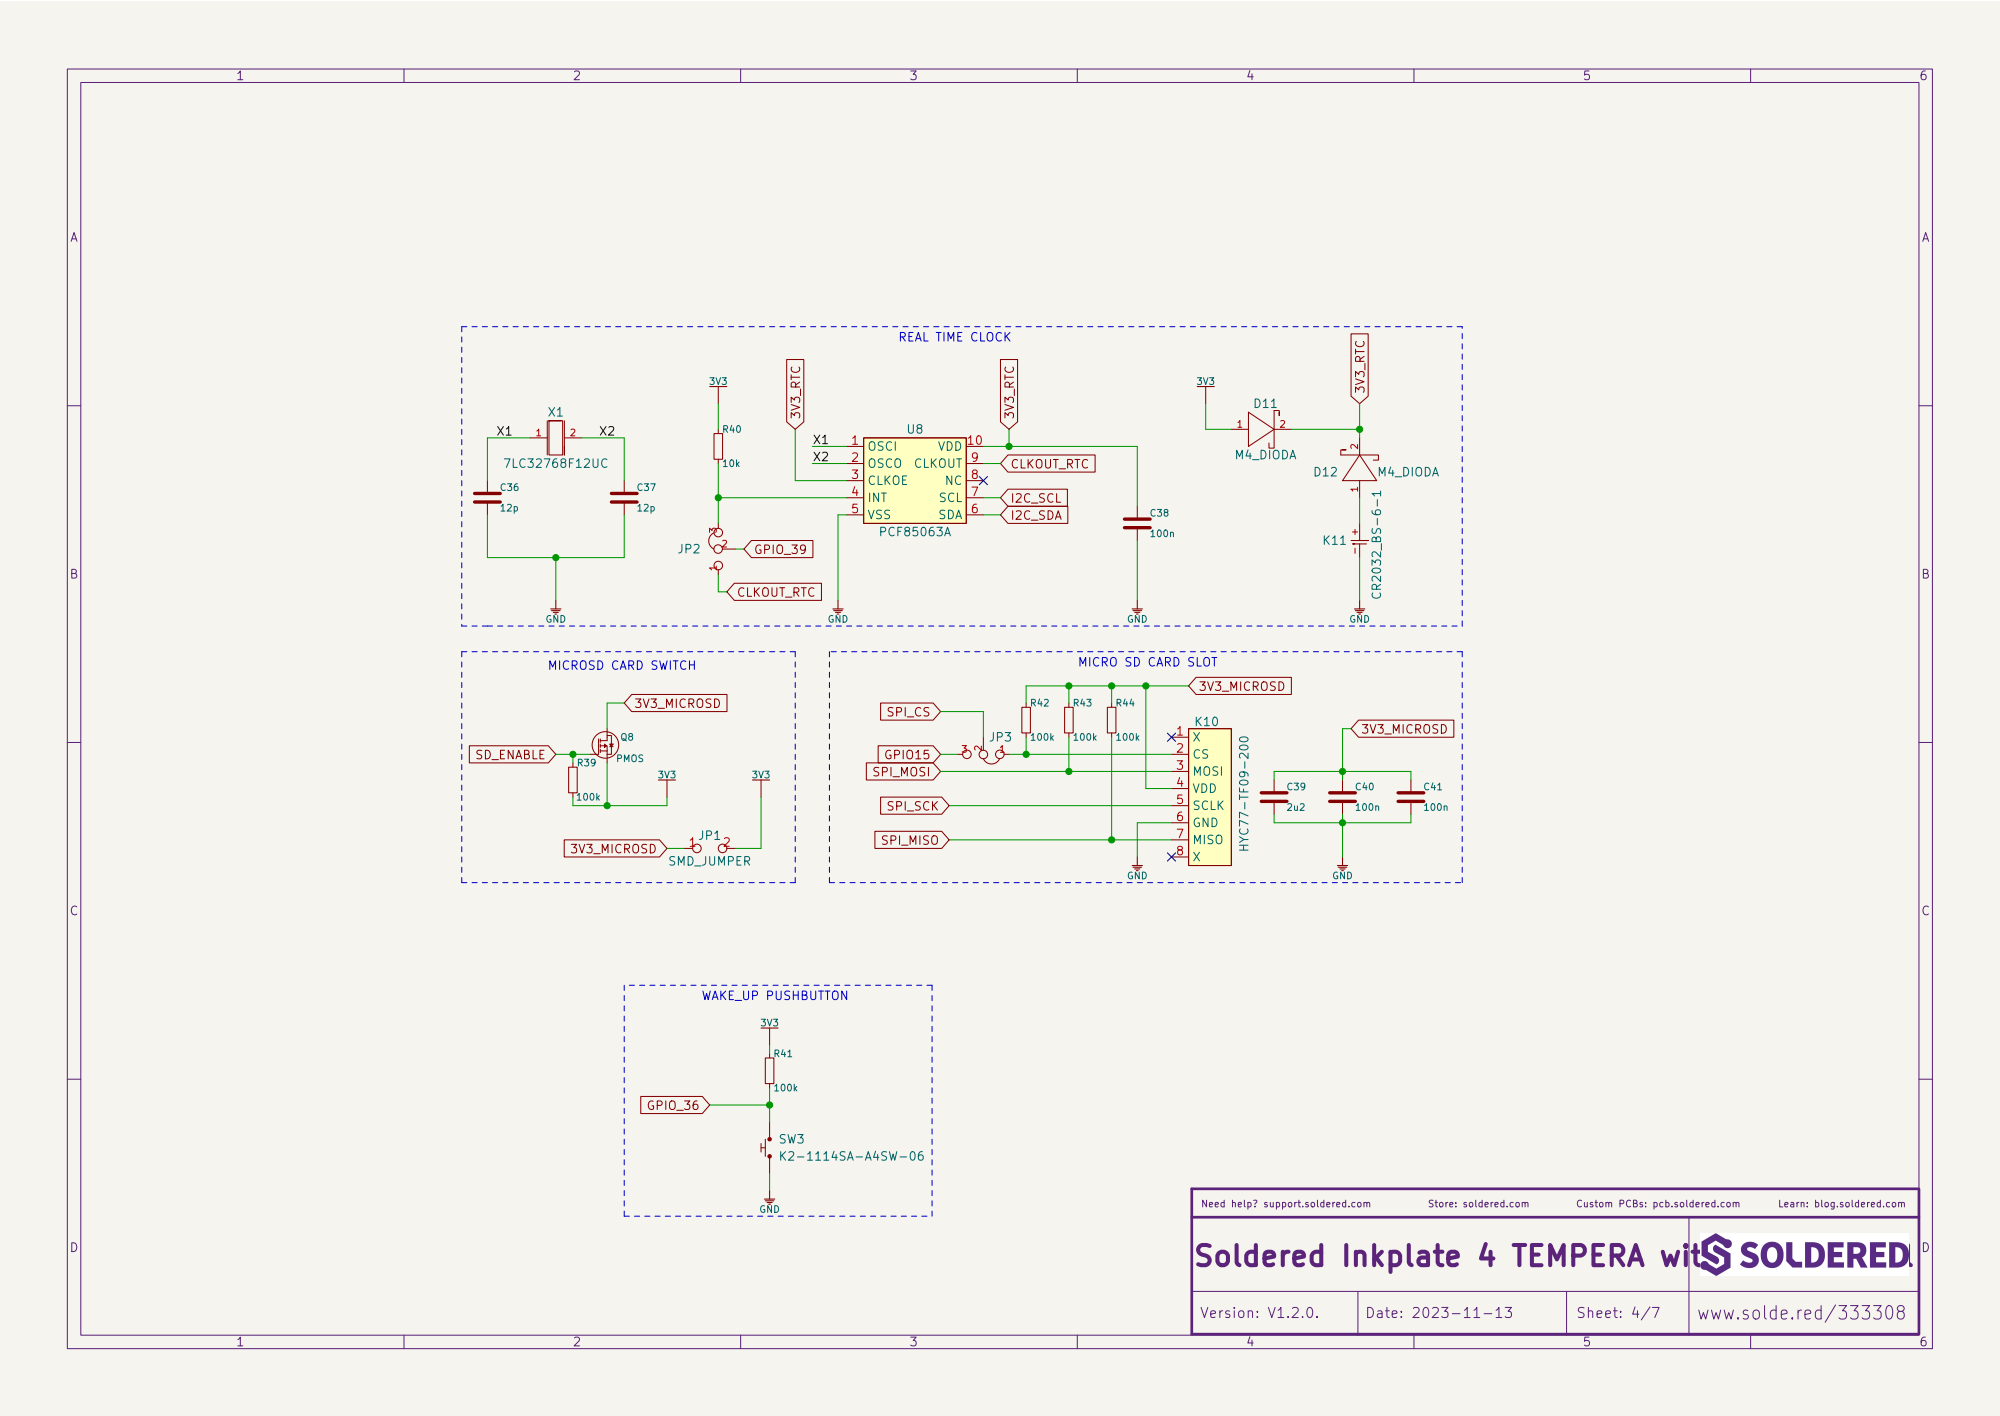
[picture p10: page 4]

Learn: blog.soldered.com

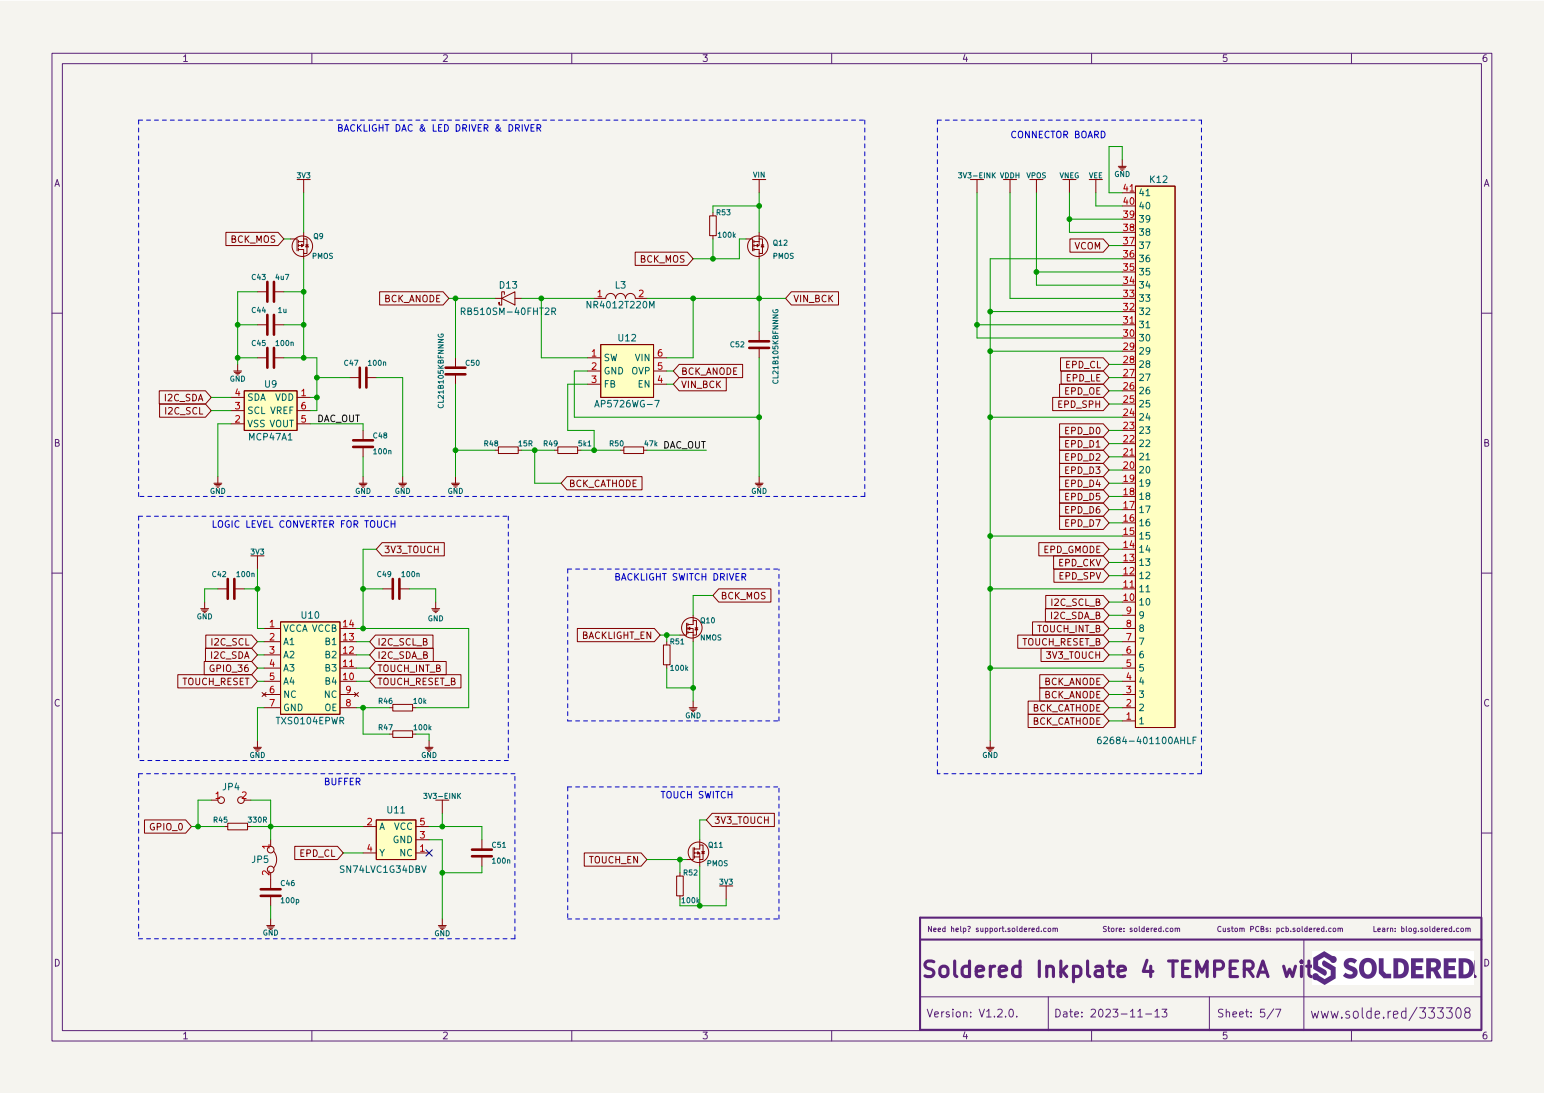
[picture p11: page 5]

BACKLIGHT DAC & LED DRIVER & DRIVER
100k GND D13 RB510SM-40FHT2R

LOGIC LEVEL CONVERTER FOR TOUCH

Learn: blog.soldered.com

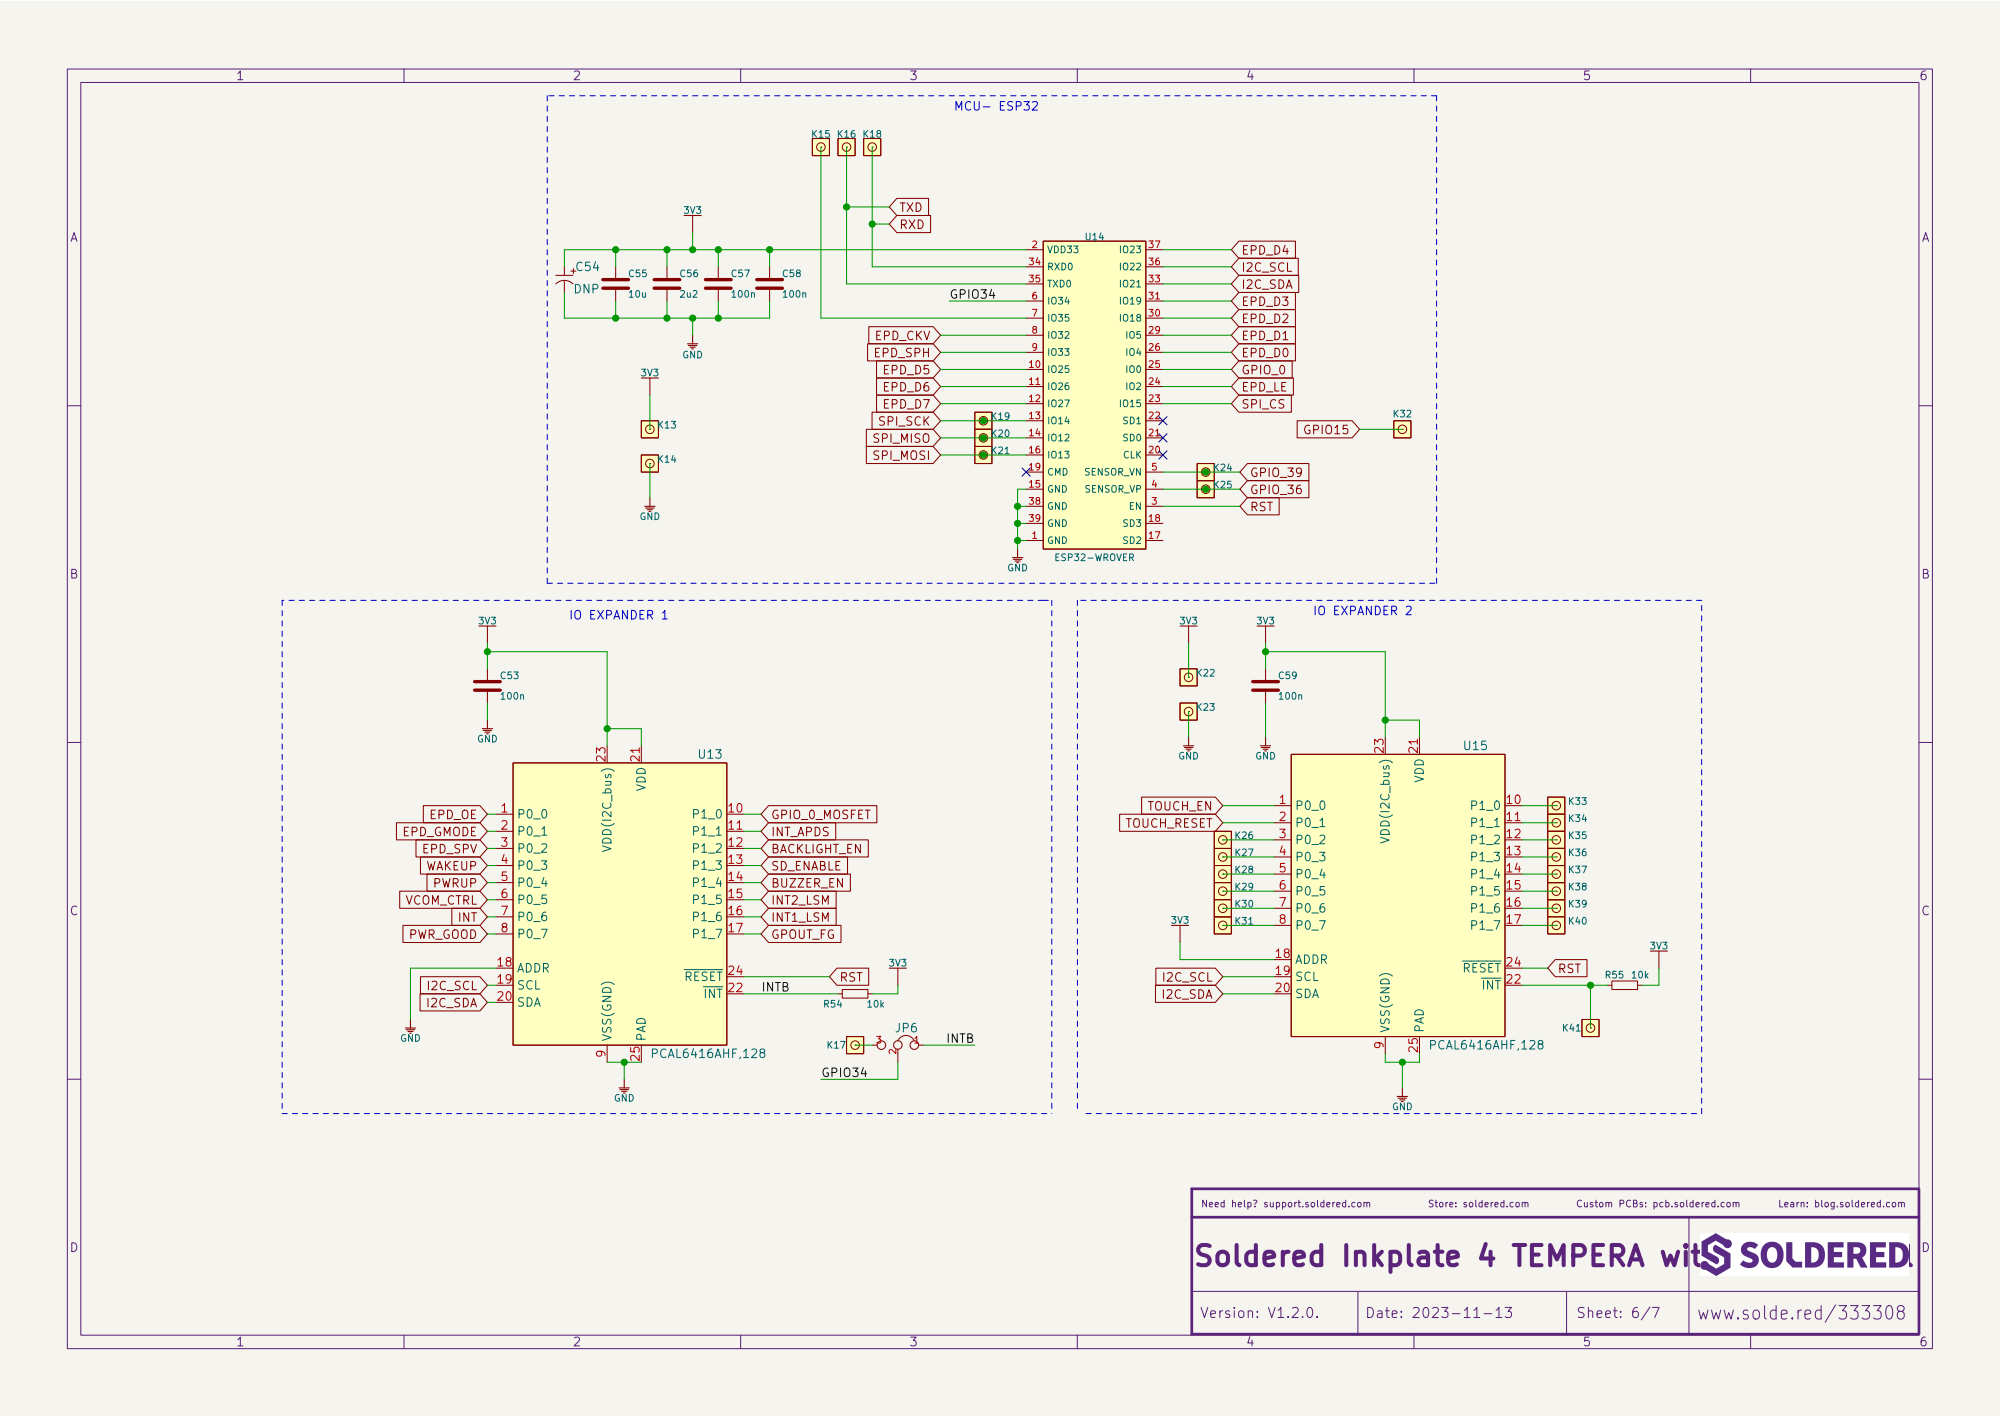
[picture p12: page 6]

Learn: blog.soldered.com

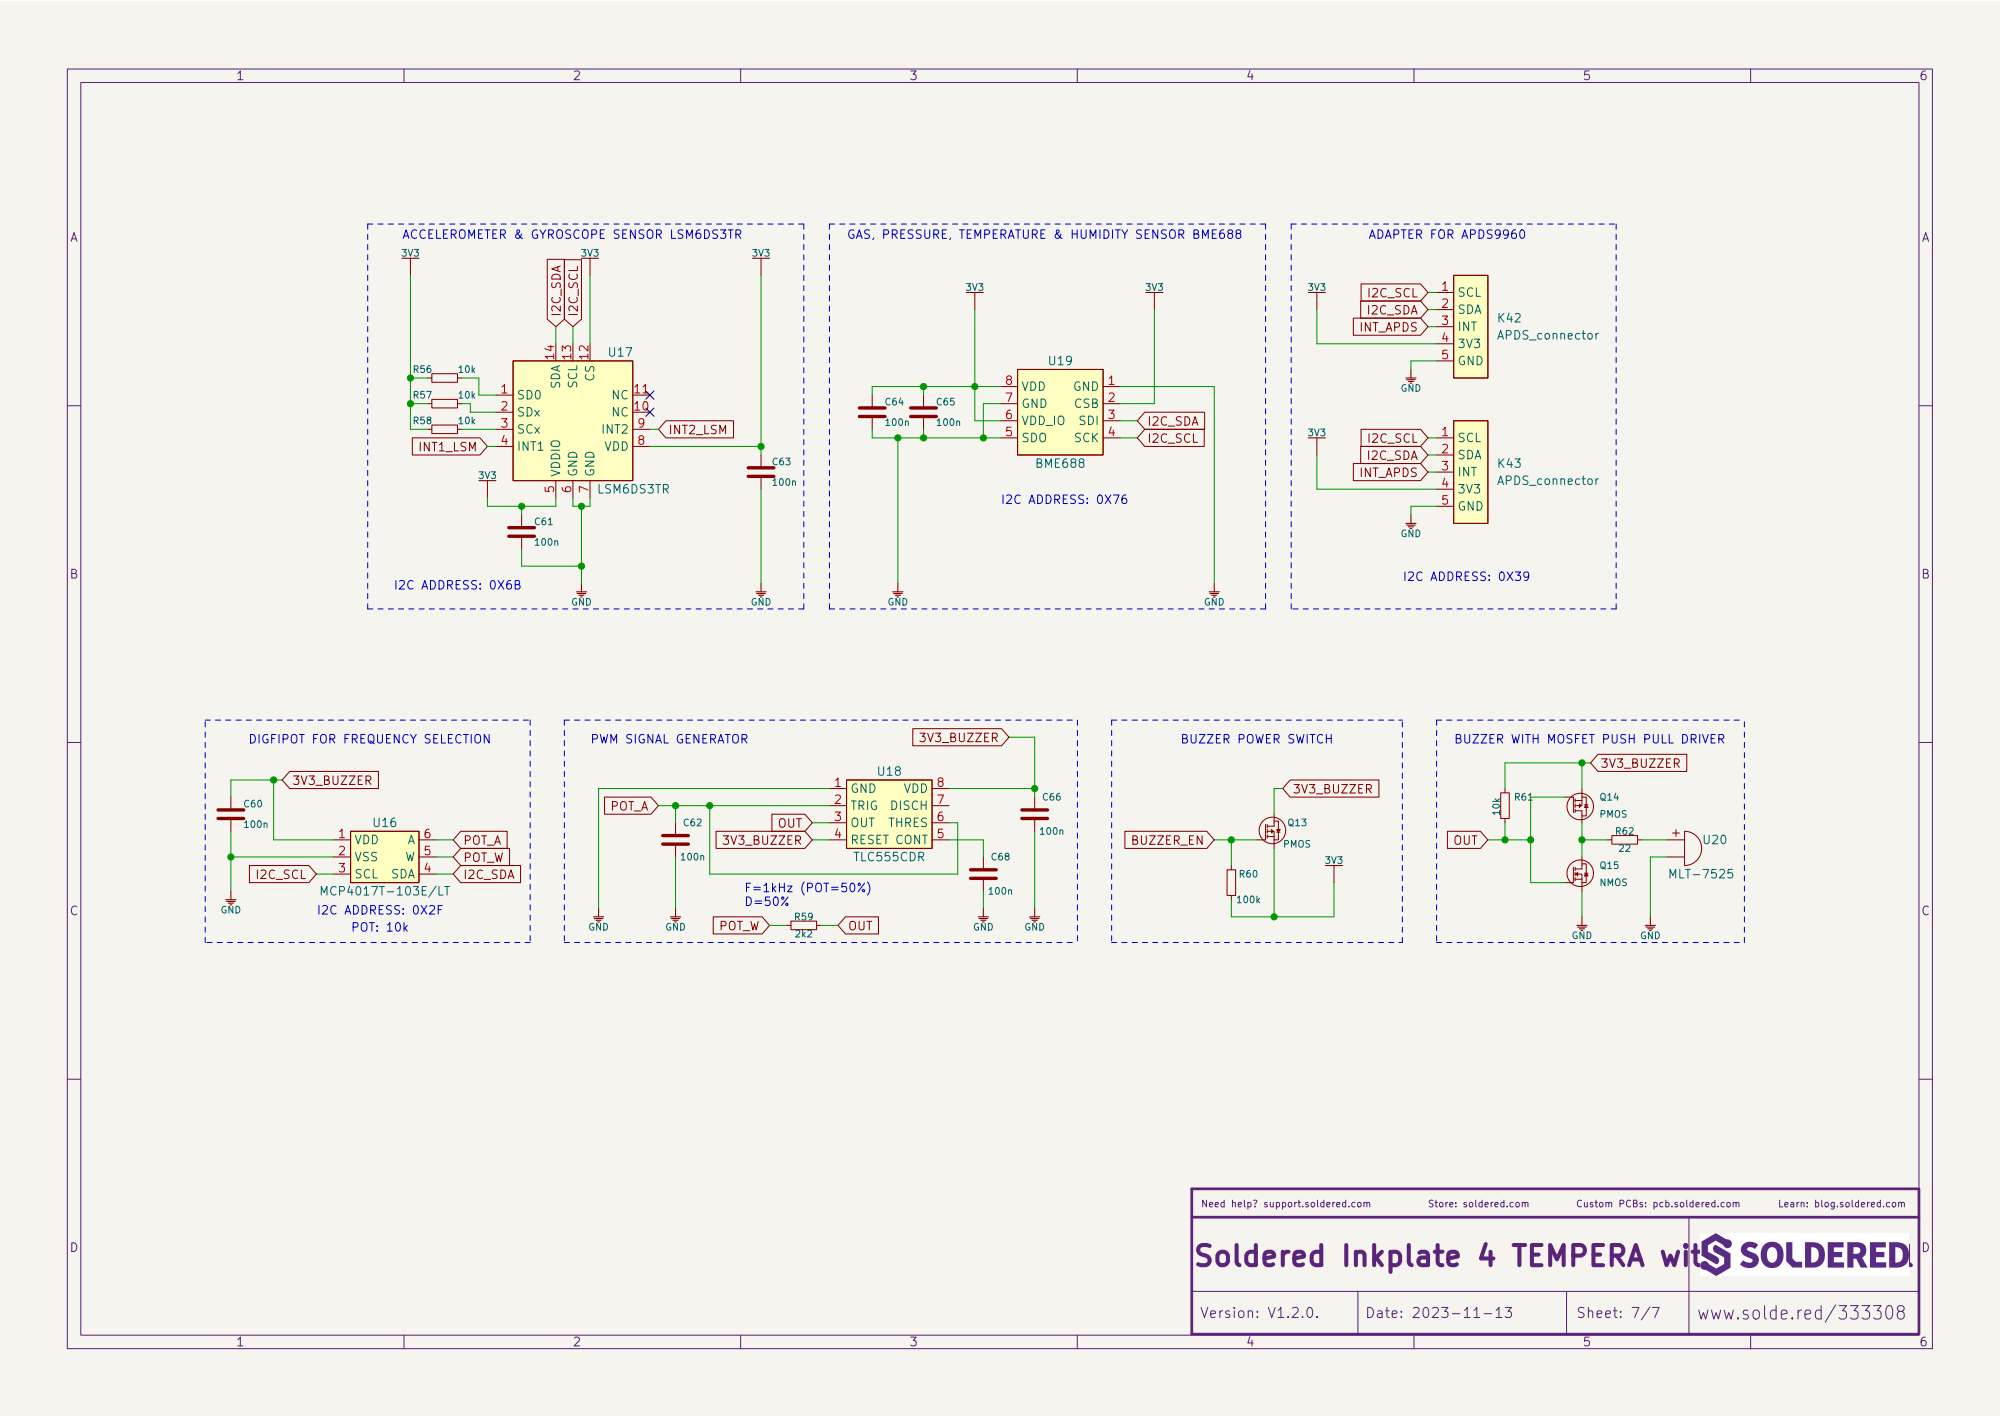
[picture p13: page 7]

I2C ADDRESS: 0X76 ACCELEROMETER & GYROSCOPE SENSOR LSM6DS3TR

BUZZER WITH MOSFET PUSH PULL DRIVER

Learn: blog.soldered.com

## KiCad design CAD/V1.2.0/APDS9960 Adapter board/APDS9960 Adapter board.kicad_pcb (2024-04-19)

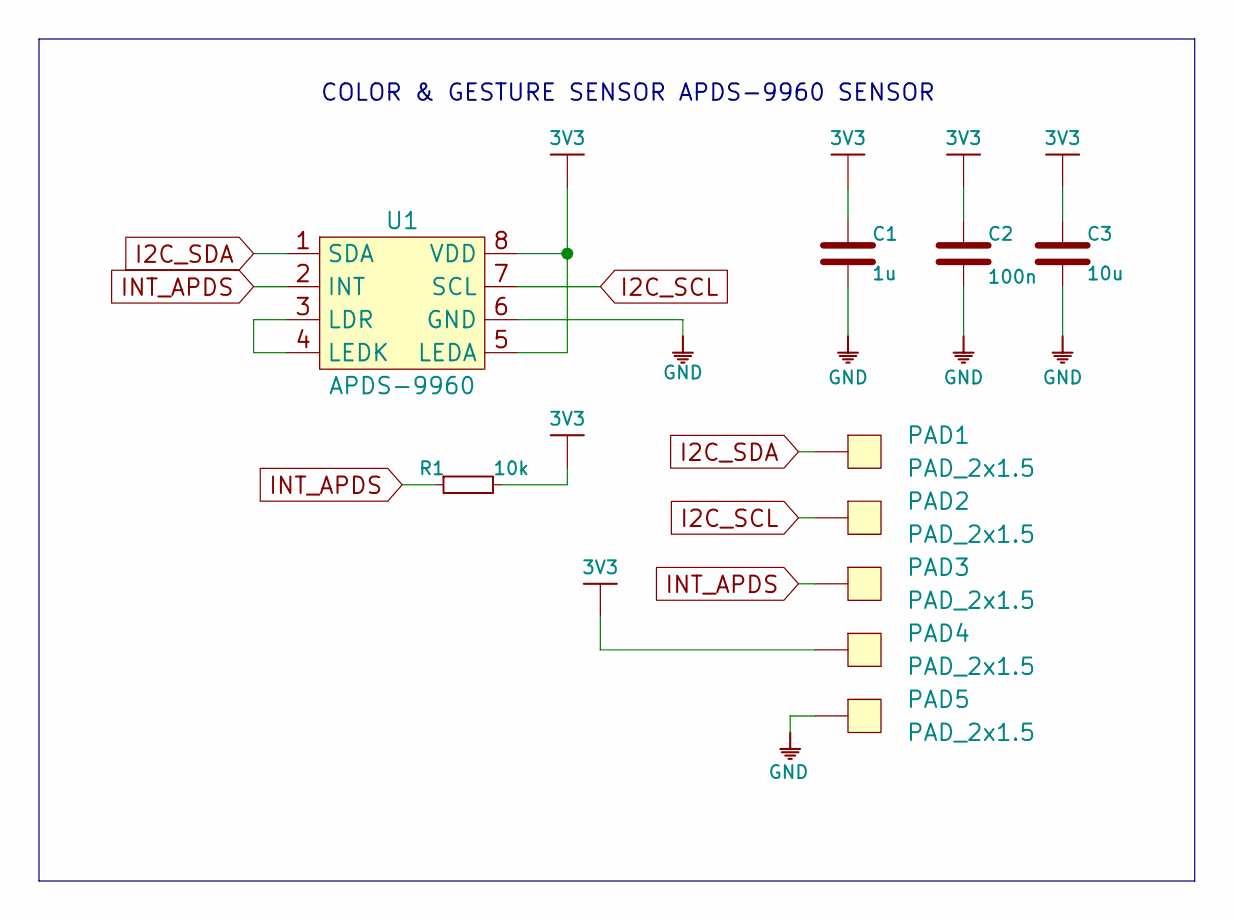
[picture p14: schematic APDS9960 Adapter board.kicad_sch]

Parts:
C1: 1u; 0603C
C2: 100n; 0603C
C3: 10u; 1206C
PAD1, PAD2, PAD3, PAD4, PAD5: PAD_2x1.5
R1: 10k; 0603R
U1: APDS-9960

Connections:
3V3: C1.2, C2.2, C3.2, PAD4.1, R1.2, U1.5 (LEDA), U1.8 (VDD)
GND: C1.1, C2.1, C3.1, PAD5.1, U1.6 (GND)
I2C_SCL: PAD2.1, U1.7 (SCL)
I2C_SDA: PAD1.1, U1.1 (SDA)
INT_APDS: PAD3.1, R1.1, U1.2 (INT)
unnamed: U1.3 (LDR), U1.4 (LEDK)

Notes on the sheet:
COLOR & GESTURE SENSOR APDS-9960 SENSOR

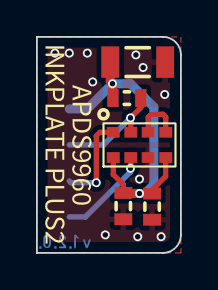
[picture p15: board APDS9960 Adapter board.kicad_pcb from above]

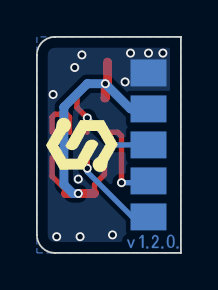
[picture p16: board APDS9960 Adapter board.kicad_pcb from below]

Board: 2 copper layers, 8.0 x 12.0 mm, 12 parts (5 on the bottom side), 6 nets.

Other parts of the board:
kibuzzard-64A9B32F: G***; kibuzzard-64A9B32F
kibuzzard-64A9B359: G***; kibuzzard-64A9B359

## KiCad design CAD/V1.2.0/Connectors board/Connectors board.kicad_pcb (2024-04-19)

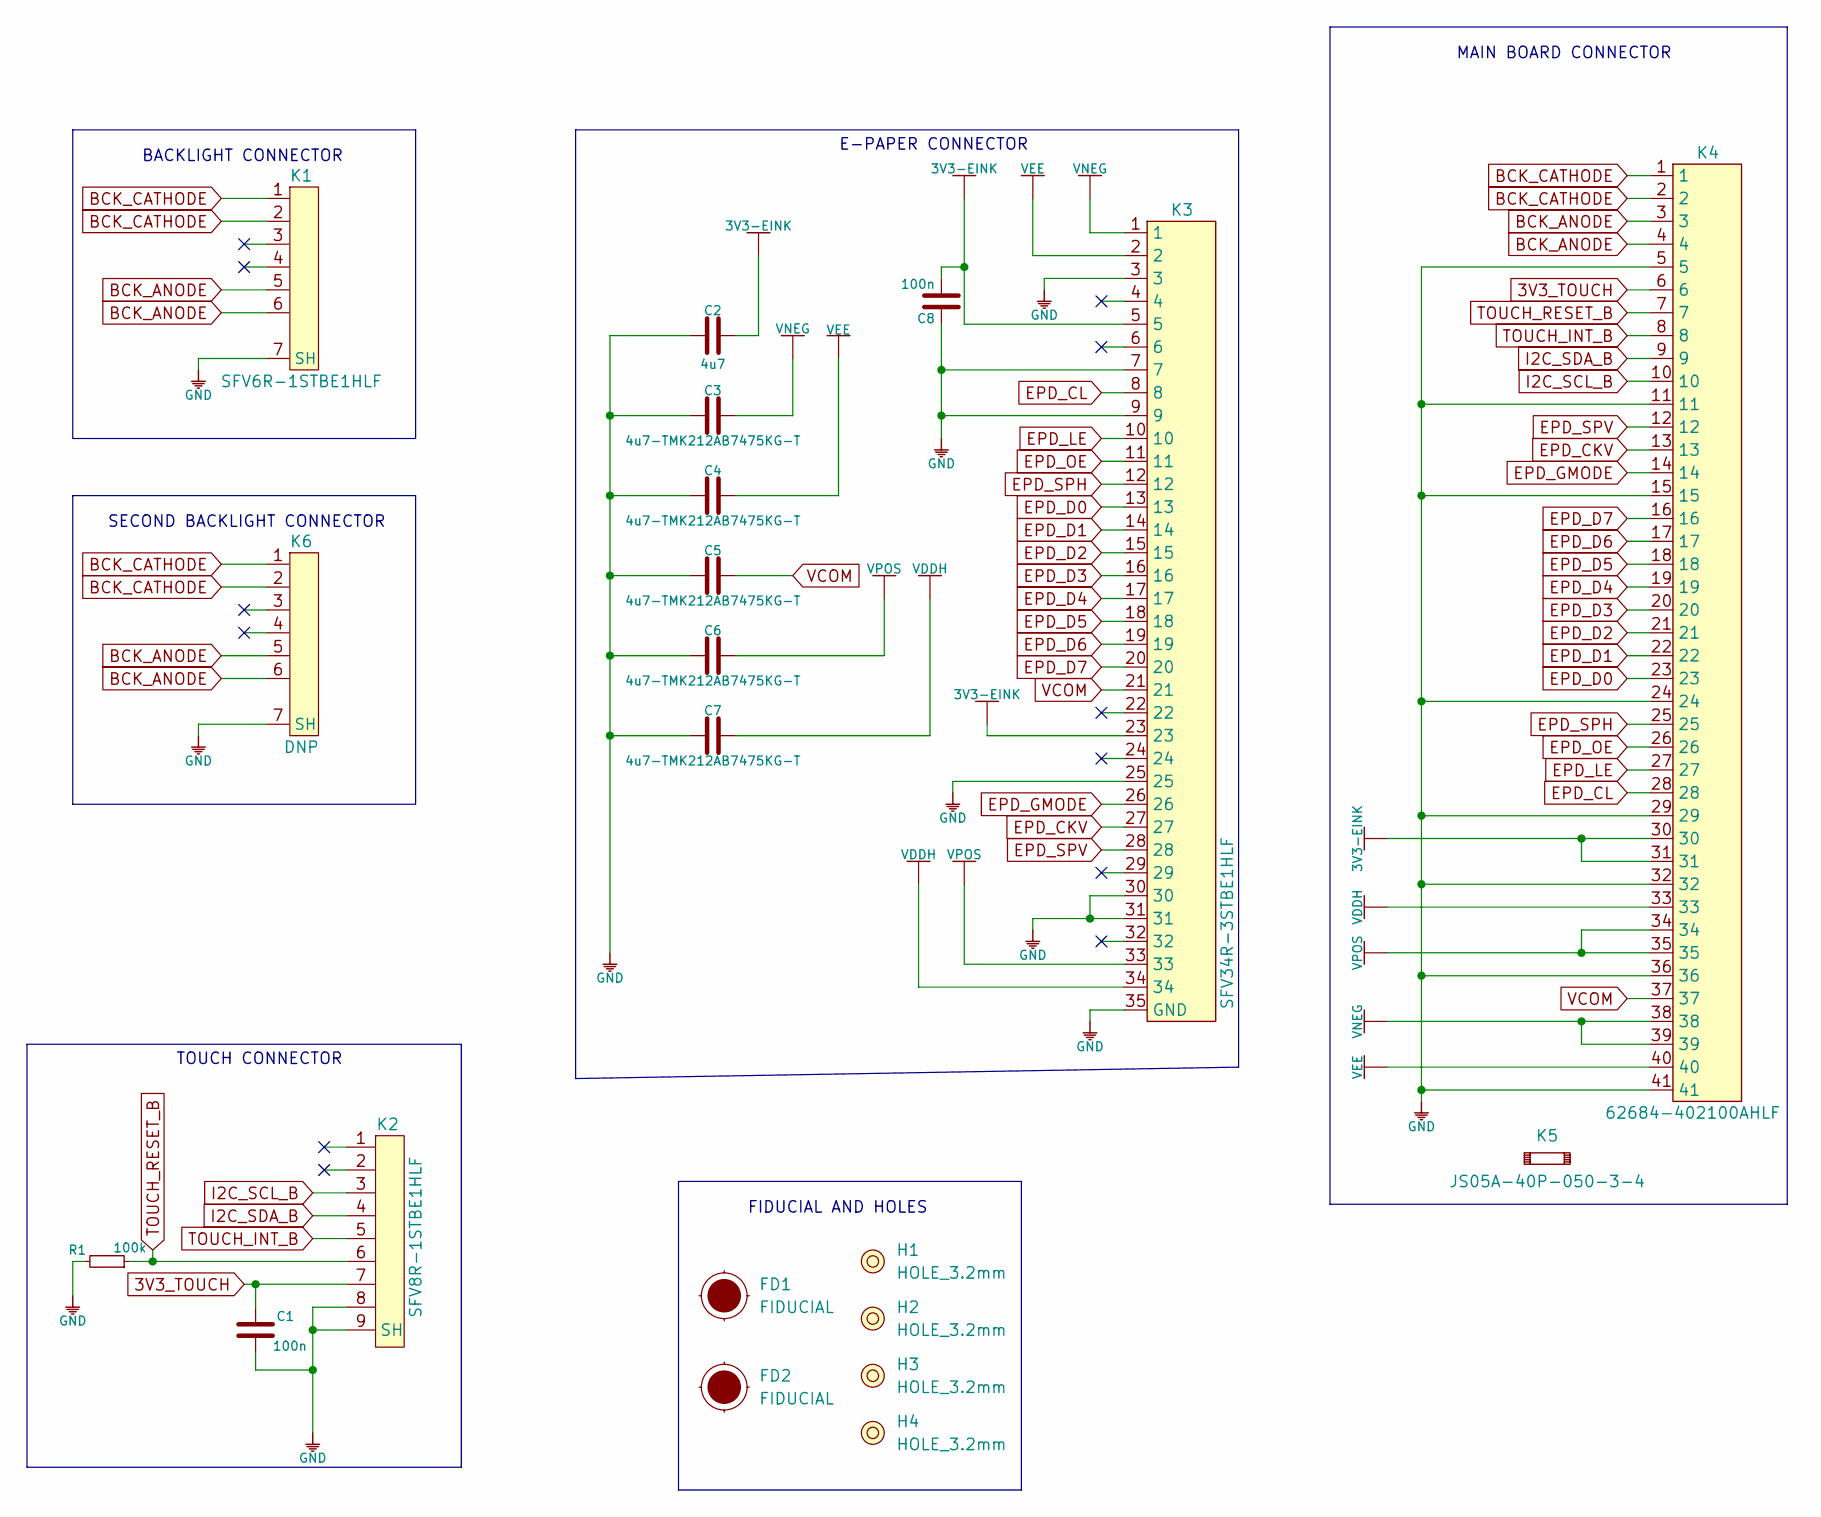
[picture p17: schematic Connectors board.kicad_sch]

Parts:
C1, C8: 100n; 0603C
C2: 4u7; 0603C
C3, C4, C5, C6, C7: 4u7-TMK212AB7475KG-T; 0805C
FD1, FD2: FIDUCIAL; FIDUCIAL_23
H1, H2, H3, H4: HOLE_3.2mm
K1: SFV6R-1STBE1HLF
K2: SFV8R-1STBE1HLF
K3: SFV34R-3STBE1HLF
K4: 62684-402100AHLF; 62684-401100AHLF
K5: JS05A-40P-050-3-4
K6: DNP; SFV6R-1STBE1HLF
R1: 100k; 0603R

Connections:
3V3-EINK: C2.2, C8.1, K3.5, K3.23, K4.30, K4.31
3V3_TOUCH: C1.2, K2.7, K4.6
BCK_ANODE: K1.5, K1.6, K4.3, K4.4, K6.5, K6.6
BCK_CATHODE: K1.1, K1.2, K4.1, K4.2, K6.1, K6.2
EPD_CKV: K3.27, K4.13
EPD_CL: K3.8, K4.28
EPD_D0: K3.13, K4.23
EPD_D1: K3.14, K4.22
EPD_D2: K3.15, K4.21
EPD_D3: K3.16, K4.20
EPD_D4: K3.17, K4.19
EPD_D5: K3.18, K4.18
EPD_D6: K3.19, K4.17
EPD_D7: K3.20, K4.16
EPD_GMODE: K3.26, K4.14
EPD_LE: K3.10, K4.27
EPD_OE: K3.11, K4.26
EPD_SPH: K3.12, K4.25
EPD_SPV: K3.28, K4.12
GND: C1.1, C2.1, C3.1, C4.1, C5.1, C6.1, C7.1, C8.2, K1.7 (SH), K2.8, K2.9 (SH), K3.3, K3.7, K3.9, K3.25, K3.30, K3.31, K3.35 (GND), K4.5, K4.11, K4.15, K4.24, K4.29, K4.32, K4.36, K4.41, K6.7 (SH), R1.2
I2C_SCL_B: K2.3, K4.10
I2C_SDA_B: K2.4, K4.9
TOUCH_INT_B: K2.5, K4.8
TOUCH_RESET_B: K2.6, K4.7, R1.1
VCOM: C5.2, K3.21, K4.37
VDDH: C7.2, K3.34, K4.33
VEE: C4.2, K3.2, K4.40
VNEG: C3.2, K3.1, K4.38, K4.39
VPOS: C6.2, K3.33, K4.34, K4.35

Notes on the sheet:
TOUCH CONNECTOR
FIDUCIAL AND HOLES
E-PAPER CONNECTOR
BACKLIGHT CONNECTOR
MAIN BOARD CONNECTOR
SECOND BACKLIGHT CONNECTOR

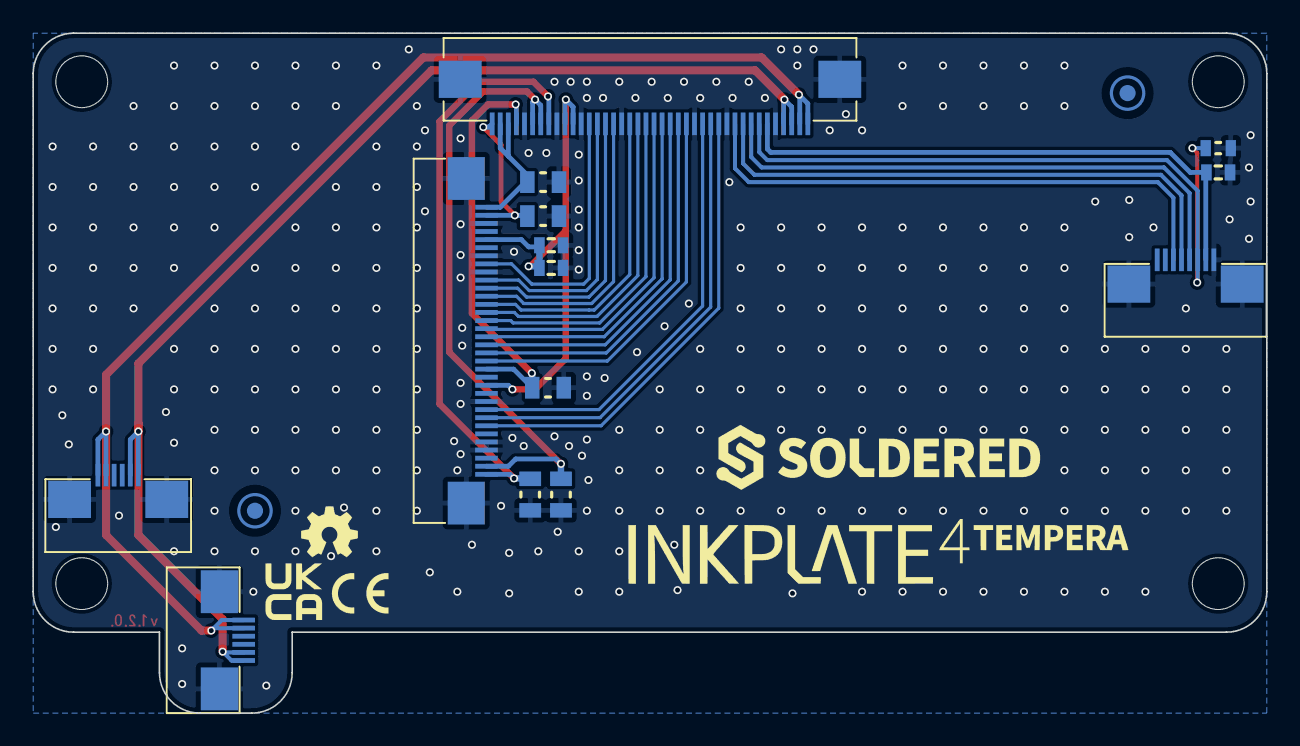
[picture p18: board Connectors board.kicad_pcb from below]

Board: 2 copper layers, 76.2 x 42.0 mm, 21 parts (16 on the bottom side), 29 nets.
